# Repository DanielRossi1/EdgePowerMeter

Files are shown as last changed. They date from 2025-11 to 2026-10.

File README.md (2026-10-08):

# EdgePowerMeter ⚡

<div align="center">

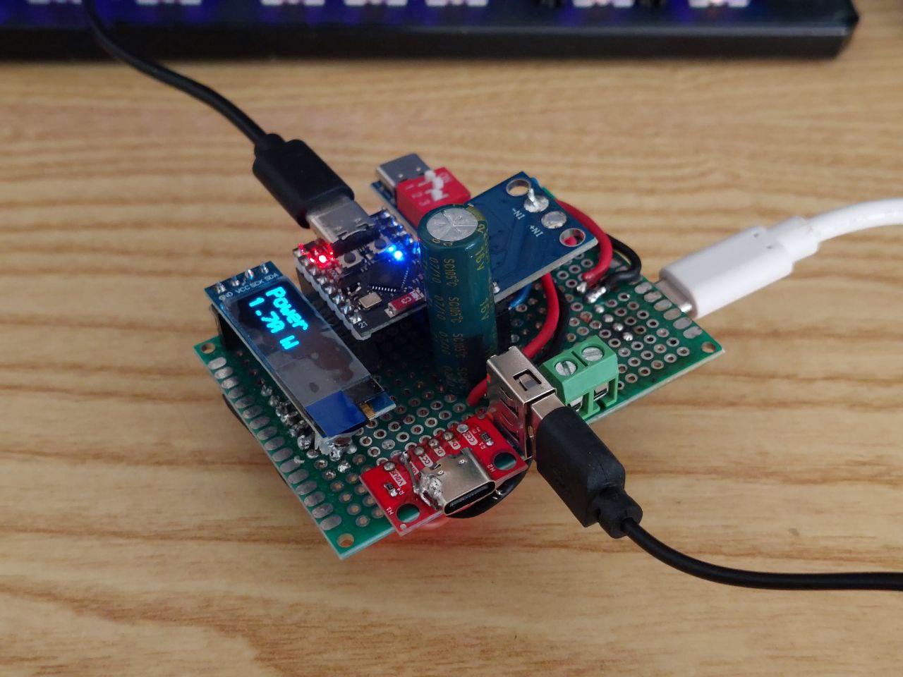
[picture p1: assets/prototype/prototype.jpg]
EdgePowerMeter Hardware


**A precision power monitoring system for embedded AI workloads**


[]()
[]()

</div>

---

## 📋 Table of Contents

- [Overview](#-overview)
- [Features](#-features)
- [Desktop Application](#-desktop-application)
- [Hardware](#-hardware)
- [Installation](#-installation)
- [Building](#-building)
- [Usage](#-usage)
- [Safety Warning](#-safety-warning)
- [License](#-license)

---

## 🔎 Overview

**EdgePowerMeter** is a complete power monitoring solution designed to measure voltage, current, and power consumption of embedded devices running AI inference workloads. Perfect for benchmarking FPS-per-Watt (FPS/W) efficiency of machine learning models at the edge.

### Why EdgePowerMeter?

- **Precision Measurements**: INA226 power monitor with configurable averaging
- **Real-time Visualization**: Modern desktop app with live graphs
- **Data Export**: CSV and PDF report generation
- **Timestamped Logs**: DS3231 RTC for accurate time synchronization
- **Open Source**: Full hardware schematics and software included

---

## ✨ Features

### Hardware
- 🔋 **INA226** high-precision power monitor (I²C)
- 🕐 **DS3231** real-time clock for accurate timestamps
- 📺 **SSD1306** OLED display (128×32) for live readings
- ⚡ **ESP32-C3** microcontroller with WiFi/BLE capability
- 🔧 **0.01Ω shunt** resistor for current sensing

### Software
- 📊 Real-time voltage, current and power plots with peak-preserving decimation (smooth even after hours at ~1 kHz)
- ⏱️ **Device-clock time base** (firmware 2.x): sample spacing, energy and spectrum are not distorted by USB/PC latency
- 🧮 **Lost-sample detection** (sequence numbers) and real-time energy, charge, min/max and average power
- 🎛️ **Remote sensor configuration**: INA226 averaging and conversion times, presets from ~2 Hz to ~900 Hz, saved on the device
- 🕐 **Clock sync** of the DS3231 with the PC, with live device–PC offset
- 🎯 **Calibration** in the app: shunt value, current zero ("zero now"), voltage/current gain and offset
- 📐 **Analysis page**: selectable range, per-quantity statistics, power supply quality (ripple, noise, load regulation, settling time) and frequency spectrum
- 🚩 **Markers**: press `M` (or right-click the plot) to mark events; every segment between markers gets duration, energy, average and peak power
- 🏁 **Benchmark mode**: energy per inference, inferences per joule and FPS/W, also net of the idle power
- 💽 **Continuous recording**: every acquisition is saved while it runs to a visible CSV file (crash-safe, no duplicates, no hidden files)
- 💾 CSV export/import (decimal comma, date/time or Unix time) and PDF reports with vector charts
- 🌍 **5 languages** (English, Italiano, Español, Français, Deutsch), automatically selected from the system, translated offline with a local model
- 🎨 Dark, light or system theme, configurable units, digits, refresh rate, time window and more
- 🔌 **Safe auto-reconnect**: after an unplug the recording continues; a manual Stop never restarts it
- ⌨️ Keyboard shortcuts (Ctrl+R, Ctrl+O, Ctrl+E, Ctrl+P, Ctrl+1…5)

---

## 🖥️ Desktop Application

The EdgePowerMeter desktop application provides a modern interface for real-time power monitoring and data analysis.

The window has a navigation rail with five pages: **Live**, **Analysis**,
**Device**, **Settings** and **About** (Ctrl+1…5).

> The screenshots show simulated demo data (idle → model load → inference at
> 10 FPS on a ~5 V rail); the Device page is taken from a real sensor.

### Live

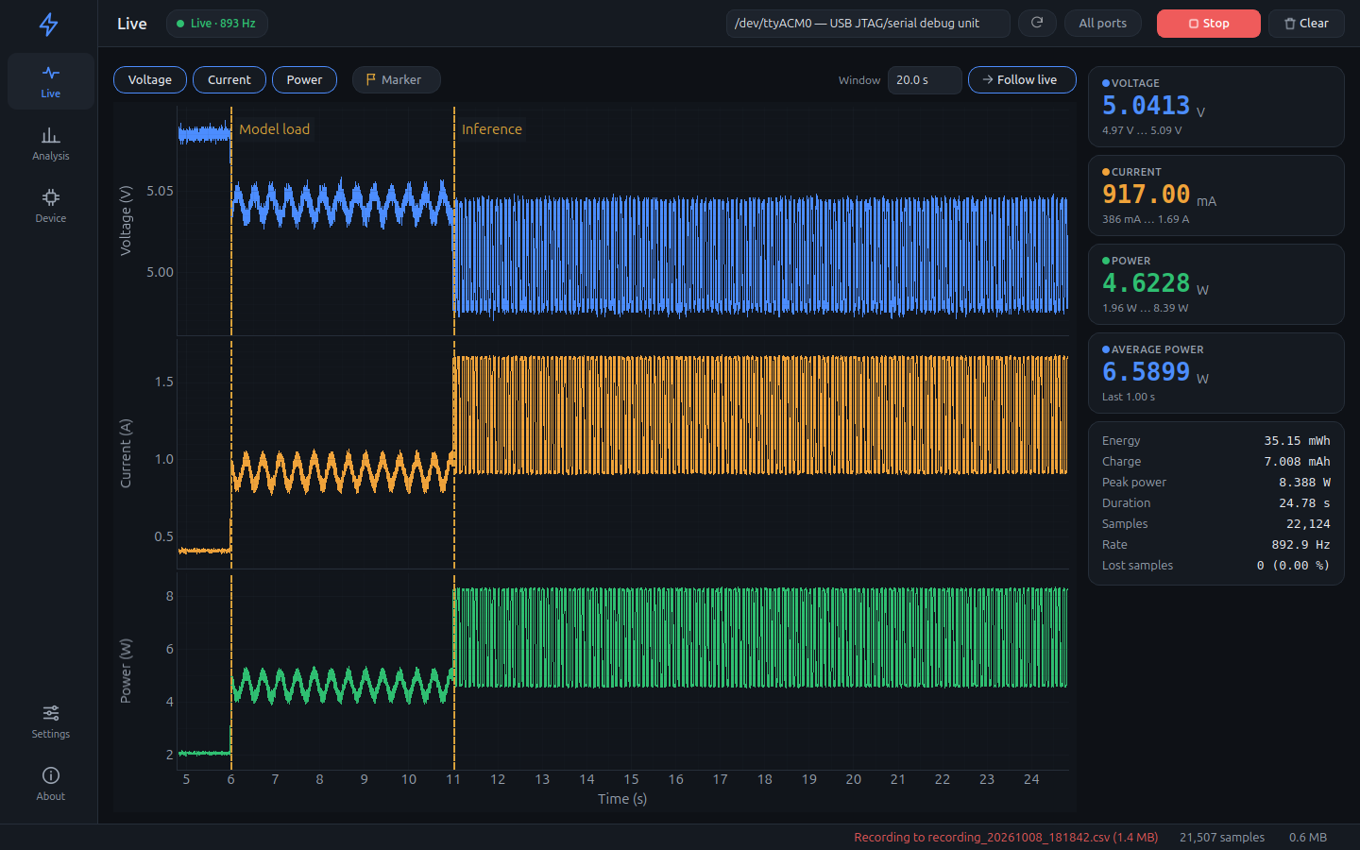
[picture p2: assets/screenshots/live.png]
Live page


Three synchronized plots (voltage, current, power) with value tiles and running
totals: energy, charge, peak power, duration, sample rate and lost samples.
Drag the plots to look back and use the mouse wheel to change the time window;
**Follow live** returns to the latest data. Press `M` (or the **Marker**
button, or right-click a plot) to mark an event. Every acquisition is written
to a CSV file while it runs, as shown in the status bar.

### Analysis

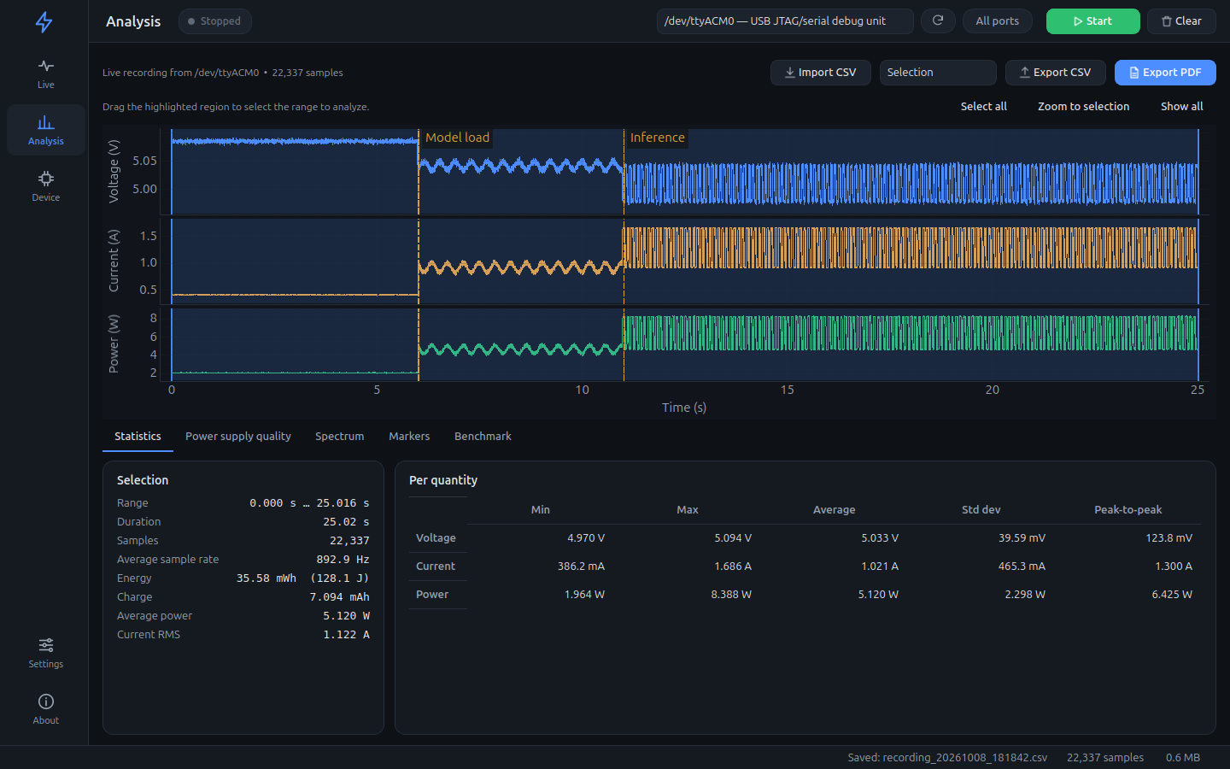
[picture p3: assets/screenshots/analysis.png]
Analysis page


Drag the highlighted region to select the range to analyze (or **Select all**),
then switch between the tabs below the plot. **Statistics** gives duration,
energy, charge, average power and current RMS of the selection plus min, max,
average, standard deviation and peak-to-peak of each quantity.

**Markers** turns the marks into segments, each with its start, duration,
average and peak power, energy and charge; click a row to select that segment.

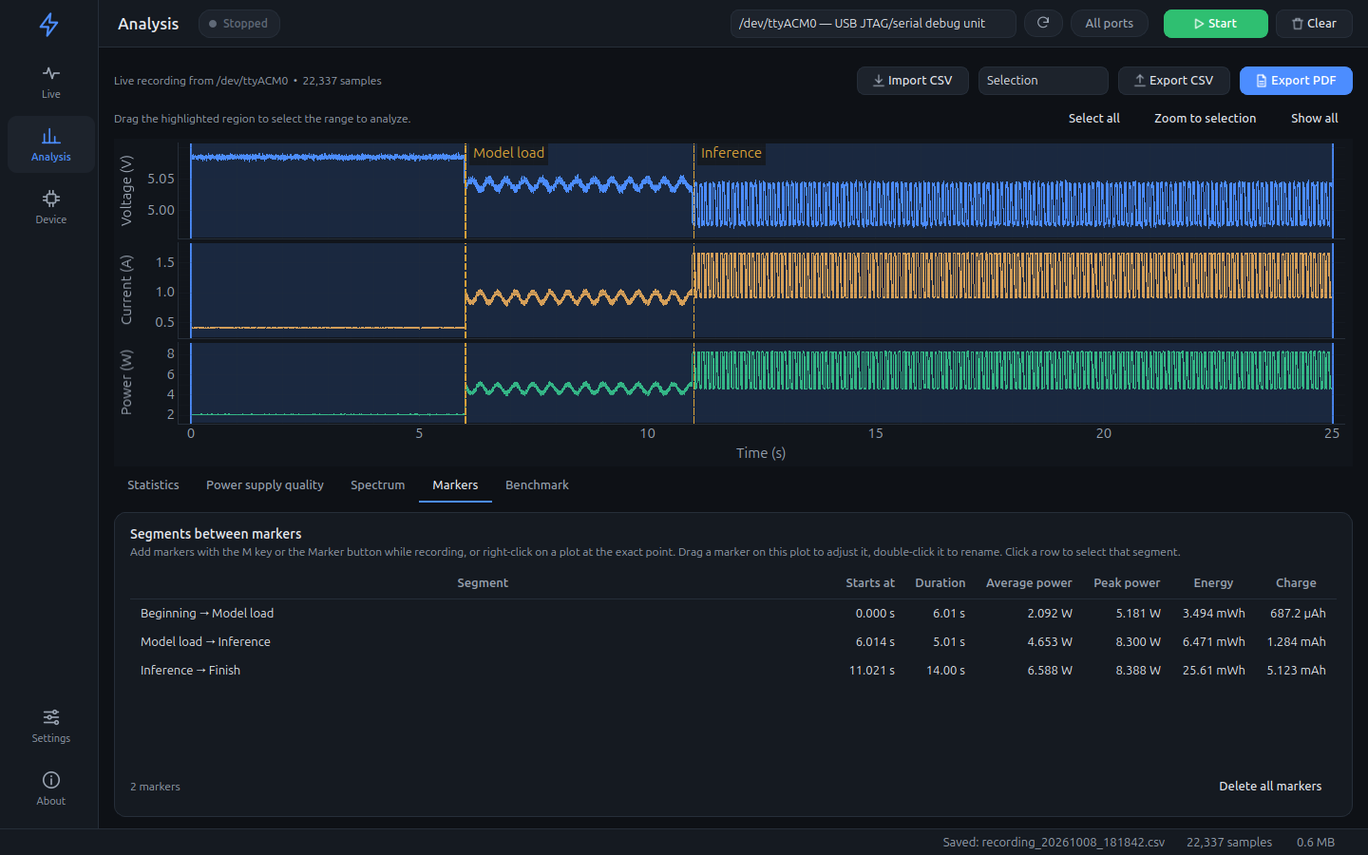
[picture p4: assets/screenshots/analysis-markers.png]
Markers tab


**Benchmark** computes energy per inference, inferences per joule and
throughput per watt (FPS/W) for the selection or a segment, also net of the
idle power measured in another segment, and can add them to the PDF report.

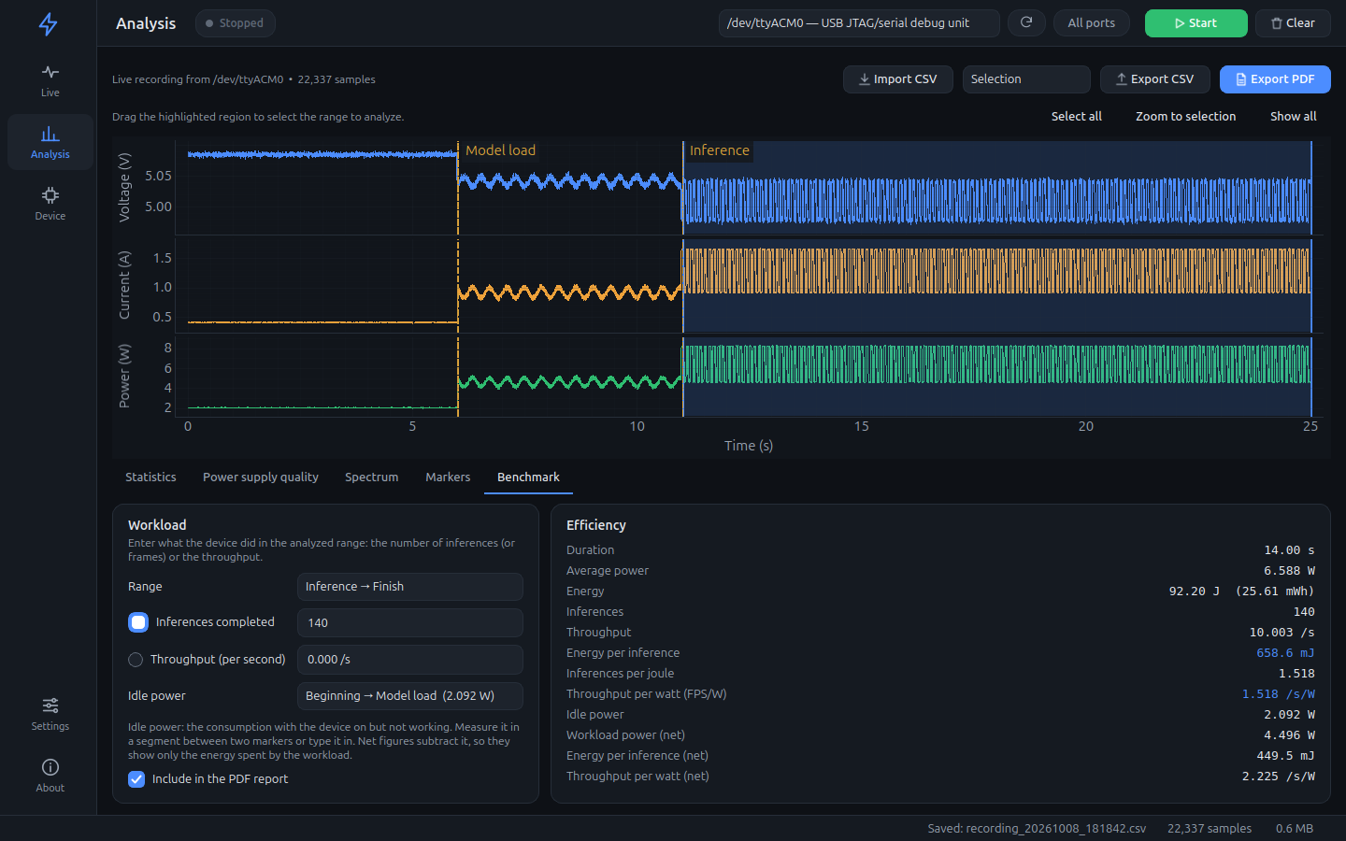
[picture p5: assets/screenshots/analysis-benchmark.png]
Benchmark tab


**Spectrum** shows where the load variation energy is concentrated (periodic
bursts, throttling cycles, regulator ripple) with the dominant frequencies;
**Power supply quality** rates the supply rail: voltage range, ripple, RMS
noise, load regulation and settling time.

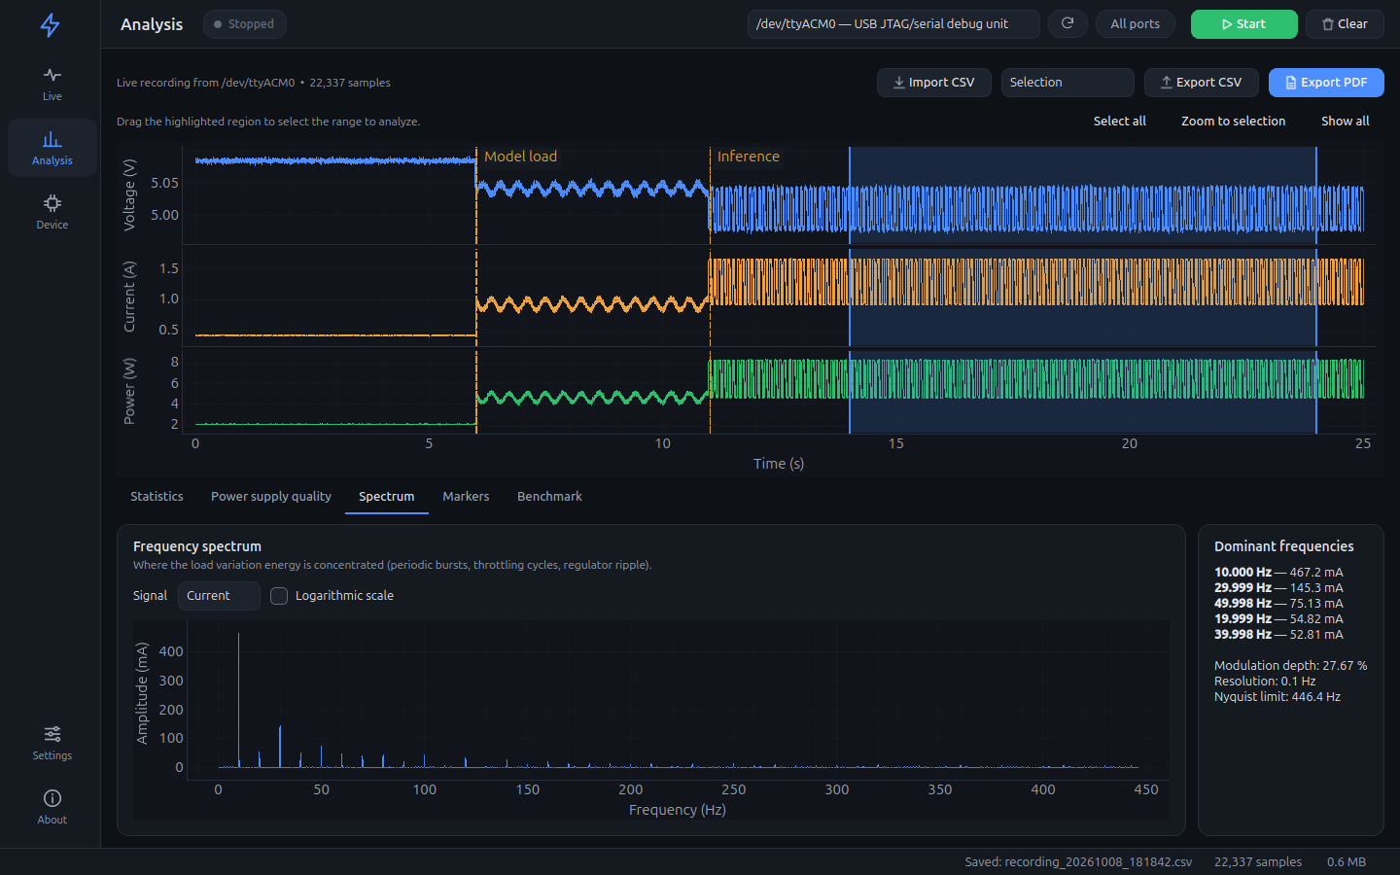
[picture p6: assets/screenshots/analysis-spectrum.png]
Spectrum tab


**Export CSV** and **Export PDF** work on the selection or the whole
recording; PDF reports include vector charts, statistics, markers, supply
quality, spectrum and benchmark results.

### Device

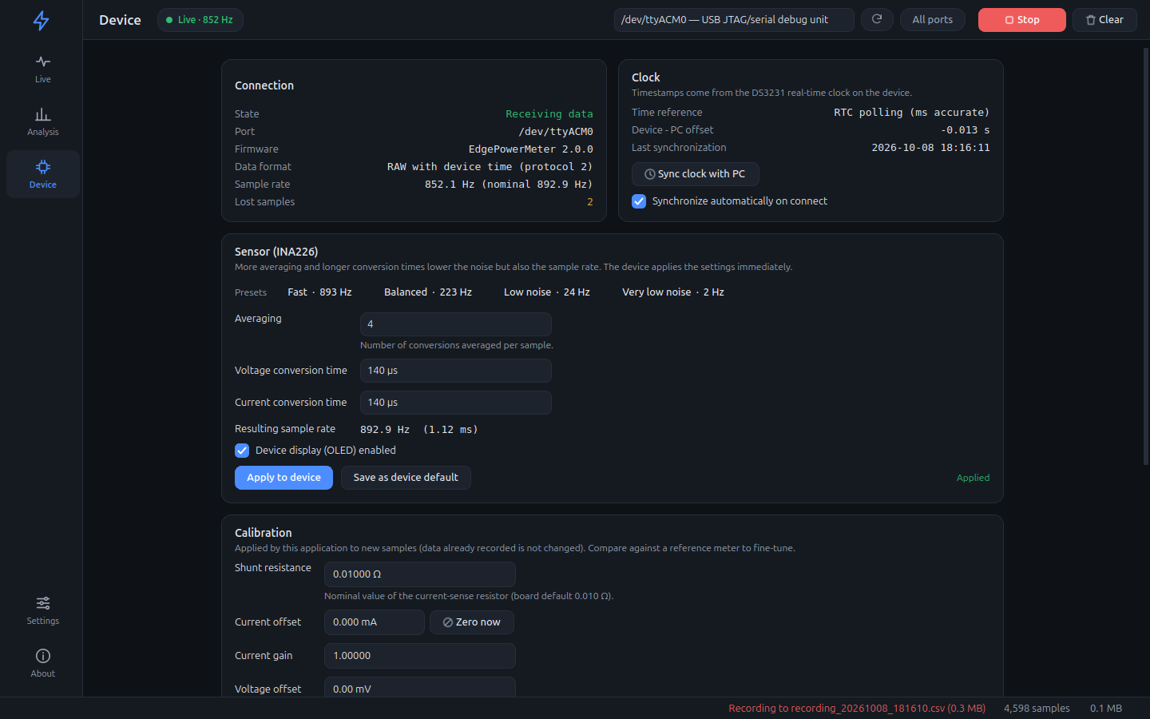
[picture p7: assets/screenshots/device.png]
Device page


Connection and firmware details, clock synchronization of the DS3231 with the
PC, INA226 averaging and conversion times (with presets from ~2 Hz to ~900 Hz,
applied immediately and optionally saved on the device) and calibration of
shunt value, current zero, gain and offset. Remote configuration and clock
sync need firmware 2.x.

### Settings

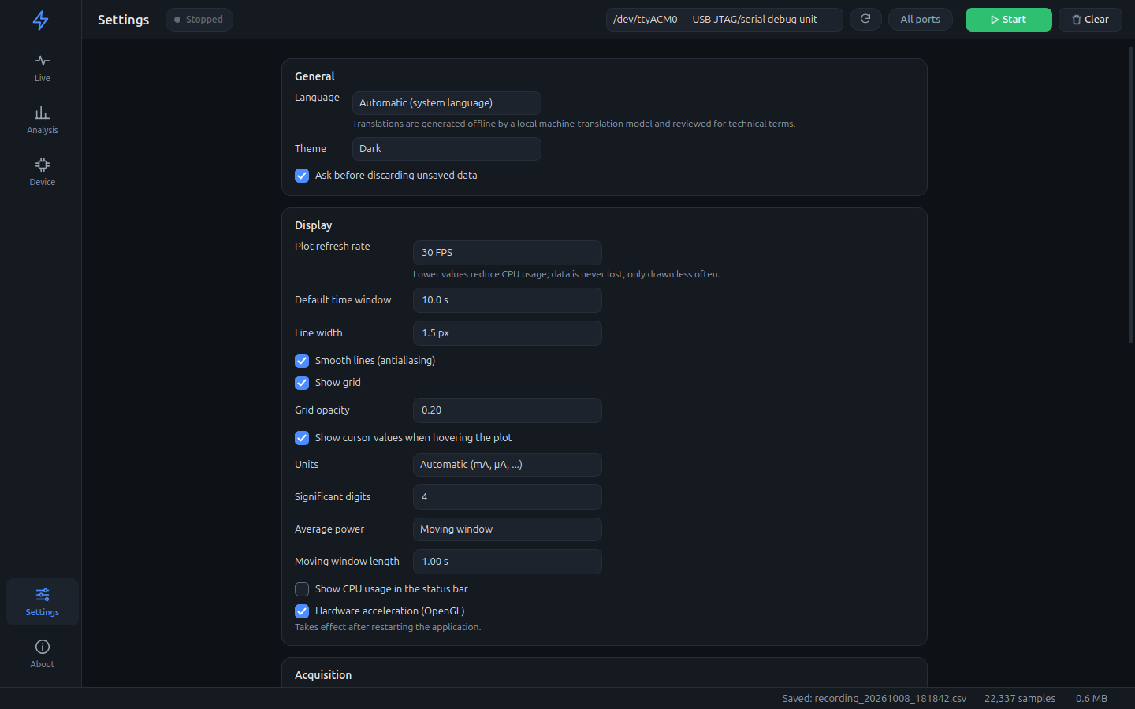
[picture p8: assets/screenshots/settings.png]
Settings page


Language, theme, plot refresh rate and time window, line width, grid, units,
significant digits, average-power mode, hardware acceleration and acquisition
options.

---

## 🧩 Hardware

### Components

| Component | Model | I²C Address | Description |
|---|---|---|---|
| MCU | ESP32-C3 SuperMini | - | Main microcontroller |
| Power Monitor | INA226 | 0x40 | Voltage/Current sensing |
| Display | SSD1306 | 0x3C | 128×32 OLED |
| RTC | DS3231 | 0x68 | Real-time clock |
| Shunt | R2512 | - | 0.01Ω current sense |

### Project Files

| File | Description |
|---|---|
| `Manufacture/BOM.csv` | Bill of Materials |
| `Manufacture/PickAndPlace.csv` | Pick and Place coordinates |
| `Schematics/EdgePowerMeter.fzz` | Fritzing schematic |
| `Schematics/EdgePowerMeter_bom.csv` | Schematic BOM |
| `firmware/firmware.ino` | Arduino firmware with libraries |

### Wiring Overview

All I²C devices share a common bus:
- **SDA**: GPIO8 (ESP32-C3)
- **SCL**: GPIO9 (ESP32-C3)
- **VCC**: 3.3V common rail
- **GND**: Common ground

The INA226 monitors voltage across the shunt resistor via `VIN+` (high side) and `VIN-` (low side).

---

## 📦 Installation

### Pre-built Binaries

Download the latest release for your platform from the [Releases](https://github.com/DanielRossi1/EdgePowerMeter/releases) page:

| Platform | File |
|---|---|
| Linux (Snap Store) | `sudo snap install edgepowermeter` |
| Linux (Debian/Ubuntu) | `edgepowermeter_x.x.x_amd64.deb` |
| Linux (Other) | `EdgePowerMeter` (standalone) |
| Windows | `EdgePowerMeter.exe` |
| macOS (Intel) | `EdgePowerMeter-macos-x86_64.zip` |
| macOS (Apple Silicon) | `EdgePowerMeter-macos-arm64.zip` |

#### Linux (Snap Store) - Recommended
```bash
sudo snap install edgepowermeter
sudo snap connect edgepowermeter:raw-usb  # Required for USB serial access
edgepowermeter
```

#### Linux (.deb)
```bash
sudo dpkg -i edgepowermeter_1.0.0_amd64.deb
edgepowermeter
```

#### Linux (standalone)
```bash
chmod +x EdgePowerMeter
./EdgePowerMeter
```

### From Source

```bash
# Clone the repository
git clone https://github.com/DanielRossi1/EdgePowerMeter.git
cd EdgePowerMeter

# Create a virtual environment and install the app with its dependencies
python3 -m venv .venv
.venv/bin/pip install -e .          # PySide6, pyqtgraph, pyserial, reportlab, numpy, PyOpenGL

# Run the application
.venv/bin/python run.py
```

### Firmware

#### Arduino IDE
1. Install ESP32 board support
2. Install required libraries:
   - `Adafruit_GFX`
   - `Adafruit_SSD1306`
   - `RTClib` by Adafruit
   (the Rob Tillaart `INA226` library is no longer needed since firmware 2.0)
3. Open `firmware/firmware.ino`
4. Select board `ESP32C3 Dev Module` and set **USB CDC On Boot: Enabled**
5. Upload

#### Arduino CLI

```bash
arduino-cli compile --fqbn esp32:esp32:esp32c3:CDCOnBoot=cdc firmware
arduino-cli upload -p /dev/ttyACM0 --fqbn esp32:esp32:esp32c3:CDCOnBoot=cdc firmware
```

The desktop app also works with firmware 1.x, but device time, lost-sample
detection, sensor configuration and clock sync require firmware 2.x.

---

## 🔨 Building

To build standalone executables for distribution:

```bash
# Install build dependencies
pip install pyinstaller

# Build executable + .deb package (Linux)
python build.py all

# Or just the executable
python build.py exe
```

Output files are created in `dist/`:
- `EdgePowerMeter` - Standalone executable
- `edgepowermeter_1.0.0_amd64.deb` - Debian package

📖 **See [docs/BUILD.md](docs/BUILD.md) for detailed build instructions**, including:
- Building on Windows and macOS
- Creating installers
- CI/CD integration
- Troubleshooting

---

## 🚀 Usage

### Quick Start

1. **Connect hardware** to your computer via USB
2. **Launch the app**: `python run.py` or run the executable
3. **Select serial port** from the dropdown
4. **Click Start** to begin recording

### Serial Output Format

At boot the firmware prints human-readable CSV (also what firmware 1.x sends),
so it can be used with any serial monitor:

```
Timestamp,Voltage[V],Current[A],Power[W]
2026-10-08 12:34:56.123,5.01250,0.250000,1.253125
```

The desktop app performs a handshake and switches the device to a compact RAW
format with device time in µs, a sequence number and the raw INA226 registers.
See **[docs/PROTOCOL.md](docs/PROTOCOL.md)** for the full protocol and the
command set (`HELLO`, `GET`, `SET AVG/VCT/ICT/OLED/STREAM/SHUNT`, `SYNC`, `SAVE`).

### Reading Serial Data (Linux)

```bash
screen /dev/ttyACM0 2000000
```

### Calculating FPS per Watt

```
FPS/W = Inference_FPS / Average_Power_W
```

**Example**: 30 FPS inference with 2.5W average = **12 FPS/W**

---

## ⚠️ Safety Warning

> **⚠️ IMPORTANT**: This project involves electrical connections. Incorrect wiring can cause damage, fire, or injury.

### Precautions

- ❌ **NOT designed for AC voltages**
- 🔌 Disconnect power before changing connections
- 🔍 Verify polarity with a multimeter before powering
- ⚡ Use appropriate fuses for your application
- 💧 Keep device dry and away from conductive materials
- 👨‍🔧 Seek professional help if unsure

**The author assumes no responsibility for damage or injury resulting from improper use.**

---

## 🛠️ Configuration

### Sensor and Calibration

With firmware 2.x, averaging and conversion times are set from the **Device**
page of the app (or with serial commands) and can be stored on the device with
*Save as device default*. Calibration (shunt value, zero offset, gain) is
applied by the app, so no reflashing is needed.

### RTC Synchronization

Use *Sync clock with PC* on the Device page (or enable automatic sync on
connect). `FORCE_RTC_UPDATE = true` in the firmware still forces a one-time sync
to the compile time.

---

## 📊 Specifications

| Parameter | Value |
|---|---|
| Voltage Range | 0 - 36V |
| Current Range | ±3.2A (with 0.01Ω shunt) |
| Resolution | 1.25 mV / 0.25 mA (2.5 µV shunt LSB) |
| Sampling Rate | ~2 Hz – ~900 Hz (configurable, default ~893 Hz) |
| Time Stamping | Device µs clock, anchored to the DS3231 SQW (±2 ppm) |
| Serial | Native USB-CDC (2000000 baud nominal) |
| Display Update | 4 Hz (non-blocking) |

---

## 📁 Project Structure

```
EdgePowerMeter/
├── firmware/                 # ESP32-C3 firmware (Arduino sketch)
│   ├── firmware.ino          # Sampling loop, protocol, commands
│   ├── INA226Lite.h/cpp      # Minimal INA226 driver
│   ├── PrecisionTime.h/cpp   # DS3231 SQW time anchors
│   └── OLEDStatus.h/cpp      # Non-blocking OLED display
├── app/
│   ├── main.py               # Bootstrap (GPU preflight, QApplication)
│   ├── core/                 # Samples store, statistics, PSU quality, spectrum, settings
│   ├── serial/               # Port I/O, protocol decoder, reader thread
│   ├── export/               # CSV import/export, PDF report, unit formatting
│   ├── i18n/                 # Runtime translations + generated catalogs
│   └── ui/                   # Main window, controller, pages, widgets, theme
├── tools/i18n/               # Offline machine-translation tool
├── tests/                    # pytest suite (headless, fake device)
├── docs/                     # BUILD, HARDWARE, SOFTWARE, PROTOCOL
├── Manufacture/              # PCB production files
└── Schematics/               # Circuit diagrams
```

---

## 🤝 Contributing

Contributions are welcome! Please feel free to submit issues and pull requests.

### TODO

- [ ] 3D printed enclosure design
- [ ] Mobile app companion
- [ ] Data logging to SD card
- [ ] Improved PCB design

---

## 📜 License

This project is licensed under the **Apache License 2.0** - see the [LICENSE](LICENSE) file for details.

---

<div align="center">

**Made with ❤️ for the embedded AI community**

⭐ Star this repo if you find it useful!

</div>

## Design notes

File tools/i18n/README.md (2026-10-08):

# Translations (i18n)

The app's UI text is written in English and wrapped in `tr()`:

```python
from app.i18n import tr, N_
button.setText(tr("Start"))
status.setText(tr("No data received for {seconds}s", seconds=5))
COLUMNS = [N_("Voltage"), N_("Current")]  # marked now, translated later with tr(col)
```

At runtime `app/i18n` only reads `app/i18n/locales/<code>.json`. Those catalogs
are generated **offline, on your machine**, with Argos Translate models run
through CTranslate2 (no cloud service, no torch).

## Workflow

```bash
# one-time setup (separate venv, gitignored)
python3 -m venv tools/i18n/.venv
tools/i18n/.venv/bin/pip install -r tools/i18n/requirements.txt

# after changing UI strings
tools/i18n/.venv/bin/python tools/i18n/translate.py extract              # -> tools/i18n/strings.json
tools/i18n/.venv/bin/python tools/i18n/translate.py translate --prune    # fills locales/*.json
tools/i18n/.venv/bin/python tools/i18n/translate.py check                # missing/stale report
```

The first `translate` downloads the en→it/es/fr/de models (~85–100 MB each)
into `~/.cache/edgepowermeter-i18n`. After that it runs fully offline.

Only strings missing from a catalog are machine-translated, so existing
entries (including hand edits) are kept. `--prune` drops entries whose
English source no longer exists.

## Fixing bad translations

Machine translation handles sentences well but often gets short UI labels
and electrical terms wrong ("Current" → "Actuellement", "Shunt" → "shock").
Put corrections in `app/i18n/overrides/<code>.json` (`{english: fixed}`).
Overrides are merged on every `translate` run and always win over the
machine output.

## Protected text

`{placeholders}`, bracketed units (`[V]`, `(mA)`), units after a value
(`5 s`, `{value} V`) and technical names (INA226, CSV, PDF, Hz, mW, ...) are
swapped for tokens before translation and restored afterwards. If the model
mangles a placeholder, the string is left in English and a warning is printed.

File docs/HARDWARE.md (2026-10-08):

# EdgePowerMeter Hardware Documentation

This document provides detailed information about the EdgePowerMeter hardware design.

## Table of Contents

1. [Overview](#overview)
2. [Components](#components)
3. [Circuit Design](#circuit-design)
4. [Wiring Schematic](#wiring-schematic)
5. [PCB Files](#pcb-files)
6. [Assembly](#assembly)
7. [Calibration](#calibration)
8. [Troubleshooting](#troubleshooting)

---

## Overview

EdgePowerMeter is a precision power measurement device based on the INA226 current/voltage monitor. It's designed to measure power consumption of embedded devices, particularly for AI inference benchmarking.

### Prototype

EdgePowerMeter Prototype

*The assembled EdgePowerMeter prototype with ESP32-C3, INA226, DS3231 RTC, and SSD1306 OLED display.*

### Key Specifications

| Parameter | Value | Notes |
|---|---|---|
| Input Voltage Range | 0 - 36V | Bus voltage measurement |
| Current Range | ±3.2A | With 0.01Ω shunt |
| Voltage Resolution | 1.25mV | 16-bit ADC |
| Current Resolution | 0.25mA | Shunt LSB 2.5µV / 0.01Ω |
| Power Calculation | Host | V × I computed per sample from raw registers |
| Sampling Rate | up to ~890 Hz | Set by INA226 averaging and conversion times (default 4 × (140+140) µs) |
| Interface | Native USB-CDC | Protocol v2, see [PROTOCOL.md](PROTOCOL.md) |

---

## Components

### Bill of Materials

| Ref | Component | Value | Package | Description |
|-----|---|---|---|---|
| U1 | ESP32-C3 | SuperMini | Module | Microcontroller |
| U2 | INA226 | - | Module | Power monitor |
| U3 | SSD1306 | 128×32 | Module | OLED display |
| U4 | DS3231 | - | Module | Real-time clock |
| R1 | Shunt | 0.01Ω | R2512 | Current sense |

### Component Details

#### ESP32-C3 SuperMini

- **CPU**: 32-bit RISC-V @ 160MHz
- **Memory**: 400KB SRAM, 4MB Flash
- **Connectivity**: WiFi, BLE 5.0
- **GPIO**: 13 available pins
- **USB**: Native USB-C

#### INA226

- **Type**: Bidirectional current/power monitor
- **Interface**: I²C (address 0x40)
- **ADC**: 16-bit
- **Features**:
  - Programmable averaging (1-1024 samples)
  - Programmable conversion time
  - Alert functionality

#### DS3231

- **Type**: Precision RTC
- **Interface**: I²C (address 0x68)
- **Accuracy**: ±2ppm (0°C to +40°C)
- **Features**:
  - Temperature compensation
  - Battery backup
  - Alarm functions

#### SSD1306 OLED

- **Resolution**: 128×32 pixels
- **Interface**: I²C (address 0x3C)
- **Color**: Monochrome (white/blue)
- **Viewing Angle**: >160°

---

## Circuit Design

### Wiring Schematic

The complete wiring diagram for EdgePowerMeter:

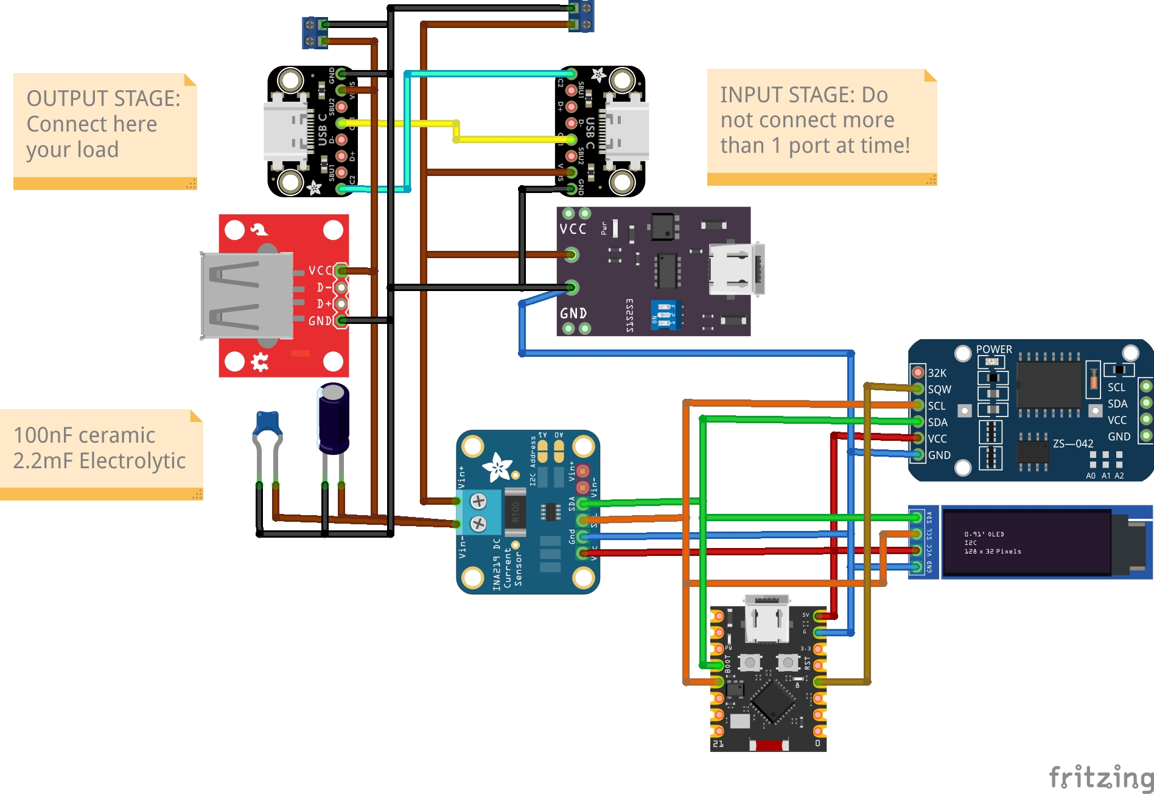
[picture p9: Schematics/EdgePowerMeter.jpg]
EdgePowerMeter Wiring Schematic


*Complete wiring schematic showing all connections between ESP32-C3, INA226, DS3231, and SSD1306.*

### Vector Schematic

For high-resolution printing or editing, an SVG version is also available:

📄 **SVG File**: [`Schematics/EdgePowerMeter.svg`](../Schematics/EdgePowerMeter.svg)

### Block Diagram

```
                    ┌─────────────┐
                    │   DS3231    │
                    │     RTC     │
                    └──────┬──────┘
                           │ I²C
┌─────────┐    ┌───────────┼───────────┐    ┌─────────┐
│  LOAD   │◄───┤         ESP32-C3      ├───►│   USB   │
│ DEVICE  │    │      (SuperMini)      │    │ (Data)  │
└────┬────┘    └───────────┬───────────┘    └─────────┘
     │                     │ I²C
     │         ┌───────────┼───────────┐
     │         │                       │
     │    ┌────┴────┐            ┌─────┴─────┐
     │    │ INA226  │            │  SSD1306  │
     │    │ Power   │            │   OLED    │
     │    │ Monitor │            │  Display  │
     │    └────┬────┘            └───────────┘
     │         │
     └─────────┤
        Shunt  │
       0.01Ω   │
               │
         ┌─────┴─────┐
         │   POWER   │
         │   SOURCE  │
         └───────────┘
```

### I²C Bus

All I²C devices share a common bus:

| Signal | ESP32-C3 GPIO | Pull-up |
|---|---|---|
| SDA | GPIO8 | 4.7kΩ |
| SCL | GPIO9 | 4.7kΩ |

### SQW Precision Timing

The DS3231 SQW (Square Wave) output provides a precise 1Hz signal for millisecond-accurate timestamps:

| Signal | ESP32-C3 GPIO | Pin Label | Function |
|---|---|---|---|
| SQW | GPIO3 | A3 | 1Hz interrupt for time sync |

**How it works:**
1. DS3231 outputs a 1Hz square wave on SQW pin; its falling edge marks the start of a new RTC second
2. ESP32 captures the falling edge in an interrupt with `esp_timer_get_time()` (µs resolution)
3. Shortly after, when the sampling loop has spare time, the RTC second is read and paired with the edge time: this is a *time anchor*
4. Every sample carries the device µs timestamp of its conversion; the host maps it to wall-clock time through the latest anchor (in RAW mode the anchors are sent once per second as `T` lines)
5. Result: µs-resolution sample timing with the DS3231's ±2ppm long-term accuracy

If no SQW edge is detected (pin not wired), the firmware falls back to polling the RTC seconds register around the expected boundary (≈ ms accuracy); the OLED status line then shows `RTC` instead of `SQW`.

### I²C Device Addresses

| Device | Address | Function |
|---|---|---|
| INA226 | 0x40 | Power monitor |
| SSD1306 | 0x3C | OLED display |
| DS3231 | 0x68 | Real-time clock |

### Power Rails

| Rail | Voltage | Source | Consumers |
|---|---|---|---|
| 3.3V | 3.3V | ESP32-C3 LDO | All I²C modules |
| VBUS | 5V | USB | ESP32-C3 |
| VLOAD | 0-36V | External | DUT (Device Under Test) |

### INA226 Connection Detail

```
POWER SOURCE (+) ──────────────┬─────────────── VIN+ (INA226)
                               │
                            ┌──┴──┐
                            │SHUNT│ 0.01Ω
                            │R2512│
                            └──┬──┘
                               │
POWER SOURCE (-) ──┬───────────┴─────────────── VIN- (INA226)
                   │
                   └─────────────────────────── LOAD (-)

LOAD (+) ──────────────────────────────────── Connected at VIN- side
```

**Important**: The load connects after the shunt resistor to measure current flowing through it.

---

## PCB Files

### Manufacturing Files

Located in `Manufacture/` directory:

| File | Description |
|---|---|
| [`BOM.csv`](../Manufacture/BOM.csv) | Bill of Materials for PCB |
| [`PickAndPlace.csv`](../Manufacture/PickAndPlace.csv) | Component placement coordinates |
| `gerber.zip` | Gerber files for PCB fabrication |

### Schematic Files

Located in `Schematics/` directory:

| File | Description |
|---|---|
| [`EdgePowerMeter.fzz`](../Schematics/EdgePowerMeter.fzz) | Fritzing project file |
| [`EdgePowerMeter.jpg`](../Schematics/EdgePowerMeter.jpg) | Wiring diagram (JPEG) |
| [`EdgePowerMeter.svg`](../Schematics/EdgePowerMeter.svg) | Wiring diagram (SVG) |
| [`EdgePowerMeter_bom.csv`](../Schematics/EdgePowerMeter_bom.csv) | Component BOM |

---

## Assembly

### Required Tools

- Soldering iron (temperature controlled)
- Fine tip (chisel or conical)
- Solder (0.5mm recommended)
- Flux (no-clean)
- Tweezers
- Multimeter
- Heat shrink tubing

### Assembly Steps

1. **Prepare Modules**
   - Verify all modules with multimeter
   - Check I²C addresses match expected values

2. **Wire I²C Bus**
   ```
   Connect in parallel:
   - SDA: All modules SDA pins
   - SCL: All modules SCL pins
   - VCC: All modules VCC pins (3.3V)
   - GND: All modules GND pins
   ```

3. **Install Shunt Resistor**
   - Use R2512 package (0.01Ω)
   - Ensure good solder joints (low resistance)
   - Verify with multimeter (should read ~0.01Ω)

4. **Connect INA226**
   - VIN+ to power source positive
   - VIN- to load positive (after shunt)

5. **Final Connections**
   - USB-C for programming and data
   - Optional: External power for higher currents

### Wiring Reference

Refer to the schematic for exact connections:

Wiring Reference

### Verification Checklist

- [ ] No shorts between VCC and GND
- [ ] I²C pull-ups installed
- [ ] All I²C addresses correct
- [ ] Shunt resistance verified
- [ ] USB connection working
- [ ] OLED displays on power-up

---

## Firmware

The sketch lives in `firmware/` (version 2.x, serial protocol v2 documented in
[PROTOCOL.md](PROTOCOL.md)).

| File | Purpose |
|---|---|
| `firmware.ino` | Main loop: sampling, serial output, command parser, NVS settings |
| `INA226Lite.h/.cpp` | Minimal INA226 driver (raw registers, conversion-ready polling) |
| `PrecisionTime.h/.cpp` | DS3231 time anchors (SQW interrupt, polling fallback) |
| `OLEDStatus.h/.cpp` | SSD1306 display with non-blocking chunked frame transfer |

**Required libraries:** `RTClib`, `Adafruit SSD1306`, `Adafruit GFX Library`
(and their dependency `Adafruit BusIO`). The Rob Tillaart `INA226` library is
**no longer required**.

**Build** (board *ESP32C3 Dev Module*, *USB CDC On Boot: Enabled*):

```bash
arduino-cli compile --fqbn esp32:esp32:esp32c3:CDCOnBoot=cdc firmware
arduino-cli upload -p /dev/ttyACM0 --fqbn esp32:esp32:esp32c3:CDCOnBoot=cdc firmware
```

**How sampling works:**
- The INA226 runs in continuous shunt+bus mode. The firmware polls its
  conversion-ready flag (the ALERT pin is not wired) and reads the shunt and
  bus registers only when a new conversion is available, so every sample is a
  fresh, non-duplicated conversion with its own µs timestamp.
- Polling starts at ~85% of the conversion period; the time before that is used
  for RTC reads and for the OLED, whose 512-byte frames are sent in 16-byte
  chunks between conversions instead of one ~13 ms blocking transfer.
- If the host stops reading, data lines are dropped instead of blocking; the
  sequence number keeps counting so the app can report lost samples.
- `loop()` never returns: the Arduino core otherwise sleeps 5 ms every 2 s
  between `loop()` calls on single-core chips (`yieldIfNecessary()`), which
  dropped ~4 conversions each time. The idle-task watchdog is disabled for
  this reason. Measured on hardware (default settings, no SQW): 0 lines lost
  and ~0.015 % conversions missed, versus ~0.4 % before.
- At boot the device prints `#`-prefixed info lines and the legacy CSV header,
  then streams in CSV mode until the app switches it to RAW mode.

---

## Calibration

With firmware 2.x the device streams the **raw** INA226 shunt and bus
registers (RAW mode); conversion to volts/amps/watts and all calibration
(shunt resistance, current offset, gain factors) happen in the desktop app,
so no reflashing is needed to calibrate.

### Shunt Resistance Calibration

1. Measure the actual shunt resistance with a precision multimeter (4-wire if possible)
2. Enter the measured value in the desktop app settings
3. Optionally store it on the device too (used only for the OLED and the legacy CSV output):
   `SET SHUNT 0.0102` followed by `SAVE`

### Current Zero Offset

1. Remove the load (open circuit)
2. Use the app's zero-offset calibration, which subtracts the measured idle current

### Voltage Scaling

1. Apply a known voltage (precision source)
2. Compare the reading with the reference and set the voltage gain in the app

### INA226 Averaging and Conversion Time

The sample period is `(VBUSCT + VSHCT) × AVG`. Configure it from the app or
with serial commands (`SET AVG <n>`, `SET VCT <µs>`, `SET ICT <µs>`, then
`SAVE` to keep it across reboots):

| AVG | Conversion time (each) | Period | Rate | Noise |
|-----|---|---|---|---|
| 1 | 140 µs | 280 µs | ~3.6 kHz* | Highest |
| 4 (default) | 140 µs | 1.12 ms | ~890 Hz | Low |
| 16 | 140 µs | 4.48 ms | ~220 Hz | Lower |
| 16 | 1100 µs | 35.2 ms | ~28 Hz | Very low |
| 64 | 1100 µs | 140.8 ms | ~7 Hz | Lowest |

\* Faster than the firmware can read and transmit every conversion: some
conversions are skipped (visible as timing gaps on the host). Periods of
about 1 ms or more leave time for the OLED refresh; with shorter periods the
OLED stops updating while sampling.

---

## Troubleshooting

### No Serial Output

1. Check USB connection
2. Verify correct COM port selected
3. Make sure the firmware was built with **USB CDC On Boot: Enabled** (the SuperMini has no USB-UART bridge)
4. Check ESP32-C3 is powered (LED on)
5. Data output may be paused (`SET STREAM 1` resumes it)

### I²C Devices Not Found

1. Check wiring continuity
2. Verify 3.3V power to all modules
3. Confirm pull-up resistors installed
4. Run I²C scanner sketch:
   ```cpp
   #include <Wire.h>
   
   void setup() {
       Wire.begin(8, 9); // SDA, SCL
       Serial.begin(115200);
       
       for(byte addr = 1; addr < 127; addr++) {
           Wire.beginTransmission(addr);
           if(Wire.endTransmission() == 0) {
               Serial.printf("Found: 0x%02X\n", addr);
           }
       }
   }
   
   void loop() {}
   ```

### Incorrect Current Readings

1. Verify shunt resistance value
2. Check current LSB configuration
3. Ensure shunt connections are solid
4. Look for ground loops

### OLED Not Working

1. Verify I²C address (0x3C for 128×32)
2. Check VCC is 3.3V
3. Try different I²C address (0x3D)
4. Check for physical damage

### RTC Wrong Time

1. Check RTC battery
2. Sync the clock from the desktop app (or send `SYNC YYYY-MM-DD HH:MM:SS` over serial)
3. Alternatively set `FORCE_RTC_UPDATE = true` in the firmware, upload, then flash back to `false`

### Power Measurement Inaccurate

1. Calibrate shunt resistance
2. Check for voltage drop in wires
3. Verify load connection point
4. Use shorter, thicker wires

---

## Safety Notes

⚠️ **WARNING**: This device is not isolated. The measurement circuit shares ground with USB.

### Safe Operating Limits

| Parameter | Maximum | Notes |
|---|---|---|
| Bus Voltage | 36V | INA226 limit |
| Continuous Current | 3A | Shunt thermal limit |
| Peak Current | 5A | Brief peaks only |
| Operating Temp | 0-70°C | Ambient |

### DO NOT

- ❌ Exceed 36V bus voltage
- ❌ Connect to AC mains
- ❌ Reverse polarity
- ❌ Create ground loops
- ❌ Operate in wet conditions

---

## References

- [INA226 Datasheet](https://www.ti.com/product/INA226)
- [DS3231 Datasheet](https://www.analog.com/DS3231)
- [ESP32-C3 Technical Reference](https://www.espressif.com/en/products/socs/esp32-c3)
- [SSD1306 Datasheet](https://cdn-shop.adafruit.com/datasheets/SSD1306.pdf)

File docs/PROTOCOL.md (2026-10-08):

# EdgePowerMeter Serial Protocol

Firmware 2.x speaks two output formats over the USB-CDC serial port
(2000000 baud nominal; the baud rate is irrelevant for native USB-CDC):

| Mode  | Purpose | Default at boot |
|---|---|---|
| `CSV` | Legacy, human-readable lines (compatible with app ≤ 1.7) | yes |
| `RAW` | Compact machine format with device time and sequence | no |

The desktop app ≥ 1.8 performs a handshake and switches the device to `RAW`.
Old firmware (1.x) ignores the handshake; the app then falls back to parsing
the legacy CSV format.

All lines are ASCII and terminated by `\n` (a preceding `\r` is tolerated).

## Device → host

### Comment / log lines

Any line starting with `#` is informational and must be ignored by parsers.
(Firmware 1.x used `[INFO] ...`, `[ERROR] ...` and `=== ... ===` lines, which
parsers must ignore as well.)

### Legacy CSV data (mode `CSV`)

```
Timestamp,Voltage[V],Current[A],Power[W]          <- header, printed once
2026-10-08 12:34:56.123,12.3450,0.1234,1.5234
```

Timestamp is the RTC wall-clock time (local time, millisecond resolution).

### Raw data (mode `RAW`)

```
D,<seq>,<t_us>,<bus_raw>,<shunt_raw>
```

| Field | Type | Meaning |
|---|---|---|
| `seq` | uint32 | Conversion counter, +1 for every conversion read from the INA226. Wraps at 2^32. A gap means samples were dropped on the device (e.g. TX buffer full). |
| `t_us` | int64  | Device monotonic time in µs since boot (`esp_timer_get_time()`) at which the conversion-ready flag was observed. Never wraps in practice. |
| `bus_raw` | uint16 | INA226 bus voltage register. LSB = 1.25 mV. |
| `shunt_raw` | int16  | INA226 shunt voltage register (signed). LSB = 2.5 µV. |

The host computes physical values (allowing user calibration):

```
V = bus_raw * 1.25e-3 * voltage_gain + voltage_offset
I = shunt_raw * 2.5e-6 / shunt_ohm * current_gain + current_offset
P = V * I
```

### Time anchor (mode `RAW`)

```
T,<t_us>,<rtc_epoch_s>,<src>
```

Emitted once per second (anchors that fail validation are skipped, so a
second can occasionally have none). `t_us` is the device time of the second boundary,
`rtc_epoch_s` the RTC time at that boundary, as seconds since 1970-01-01
**interpreting the RTC calendar as naive local time** (the RTC holds local
wall-clock time). `src` is `S` when the boundary was captured by the DS3231
SQW interrupt (µs accurate) or `P` when detected by polling (≈ ms accurate).

The host maps any sample to wall-clock time with the most recent anchor:
`wall = rtc_epoch_s + (t_us_sample - t_us_anchor) / 1e6`.

### Command replies

Every command gets exactly one reply line starting with `!`. `<COMMAND>` is
the first word of the command, upper-cased (`!OK SET`, `!OK MODE`,
`!ERR FOO unknown_command`):

```
!OK <COMMAND>
!ERR <COMMAND> <reason>
!HELLO,EdgePowerMeter,<firmware_version>,<protocol_version>
!CFG,avg=<n>,vct=<us>,ict=<us>,shunt=<ohm>,oled=<0|1>,stream=<0|1>,mode=<CSV|RAW>,sqw=<0|1>,period_us=<us>
```

`period_us` is the nominal conversion period: `(vct + ict) * avg`.

Error reasons: `missing_argument`, `invalid_value`, `unknown_parameter`,
`unknown_command`, `i2c_error`, `rtc_unavailable`, `nvs_error`,
`line_too_long` (lines over 95 characters, reported as `!ERR ? line_too_long`).

After `!OK MODE` the device re-sends the latest `T` anchor (RAW) or the CSV
header (CSV). In RAW mode a `T` anchor is also sent right after `!OK SYNC`
(the new time line) and after `!OK SET` for `SET STREAM 1`.

## Host → device commands

Case-insensitive, one per line.

| Command | Effect |
|---|---|
| `HELLO` | Identify. Replies `!HELLO,...`. |
| `GET` | Replies `!CFG,...` with the current configuration. |
| `MODE RAW` / `MODE CSV` | Select output format. |
| `SET AVG <n>` | INA226 averaging: 1, 4, 16, 64, 128, 256, 512, 1024. |
| `SET VCT <us>` / `SET ICT <us>` | Bus / shunt conversion time: 140, 204, 332, 588, 1100, 2116, 4156, 8244. |
| `SET SHUNT <ohm>` | Shunt resistance used for CSV mode and the OLED (RAW is unaffected). Accepted range 0.00001–100 Ω. |
| `SET OLED <0\|1>` | Enable/disable the OLED display. |
| `SET STREAM <0\|1>` | Pause/resume data output. |
| `SYNC YYYY-MM-DD HH:MM:SS` | Set the RTC (local time). Hosts should send it right at a second boundary. The device reads the time back and replies `!ERR SYNC i2c_error` if the write did not take. |
| `SAVE` | Persist AVG/VCT/ICT/SHUNT/OLED to flash (NVS); restored at boot. |

Changing `AVG`, `VCT` or `ICT` restarts the conversion pipeline; `seq` keeps
counting. While `STREAM 0` is active sampling continues (OLED) and `seq` keeps
counting, so hosts must not count the gap after `STREAM 1` as lost samples.

## Data loss accounting

* A `seq` gap means the device read conversions but dropped the lines because
  the USB TX buffer was full (host not reading fast enough).
* With very short conversion periods (below ~0.5 ms, e.g. `AVG 1` at 140 µs)
  the firmware cannot read every conversion; skipped conversions never get a
  `seq` and show up only as `t_us` gaps larger than `period_us`.

## Boot sequence

The device waits up to 1.5 s for the USB host, prints `#` info lines ending
with `# EdgePowerMeter v2.x.y ready (protocol 2)`, then the CSV header and CSV
data. A `HELLO` sent during boot is answered once the main loop starts. If the
INA226 is missing the device keeps running, answers commands, prints
`# ERROR INA226 not found` and retries every 5 s.

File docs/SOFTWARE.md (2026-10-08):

# EdgePowerMeter Software Documentation

Desktop application (Python, PySide6/Qt 6, pyqtgraph) for the EdgePowerMeter
hardware. This document describes the architecture and the main modules.
The serial protocol is specified in [PROTOCOL.md](PROTOCOL.md), the firmware
and hardware in [HARDWARE.md](HARDWARE.md), packaging in [BUILD.md](BUILD.md).

## Table of Contents

- [Architecture](#architecture)
- [Data path](#data-path)
- [Modules](#modules)
- [User interface](#user-interface)
- [Translations](#translations)
- [Settings](#settings)
- [Export formats](#export-formats)
- [Testing](#testing)
- [Troubleshooting](#troubleshooting)

---

## Architecture

```
            USB-CDC                    reader thread                      GUI thread
┌──────────┐  bytes  ┌───────────────────────────────────┐  Samples   ┌──────────────────────────┐
│ ESP32-C3 │ ──────► │ SerialPortHandler (select/os.read)│  batches   │ AcquisitionController     │
│ firmware │ ◄────── │ StreamDecoder  (RAW / legacy CSV) │ ─────────► │  SampleStore (numpy)      │
└──────────┘ commands│ SerialReader   (handshake, watchdog,│  ≤60/s    │  RunningStats             │
                     │                 commands, batching)│           │  reconnect logic          │
                     └───────────────────────────────────┘           └────────────┬─────────────┘
                                                                                  │ signals
                                          ┌───────────────┬───────────────┬───────┴──────┬──────────────┐
                                          │ LivePage      │ AnalysisPage  │ DevicePage   │ SettingsPage │
                                          │ plots, tiles  │ selection,    │ INA226 cfg,  │ all options  │
                                          │               │ PSU, spectrum │ clock, calib │              │
                                          └───────────────┴───────────────┴──────────────┴──────────────┘
```

Design rules:

- **No per-sample work on the GUI thread.** The reader decodes in bulk and
  emits one `Samples` batch per frame; plots redraw at a fixed rate (default
  30 FPS) and only the visible slice is handed to pyqtgraph, which
  peak-downsamples it to the pixel width.
- **Columnar storage.** Samples live in growable numpy columns
  (`SampleStore`, 28 bytes/sample), so hours of 1 kHz data stay in the
  hundreds of MB and every statistic is vectorized.
- **Device time.** With firmware 2.x the time axis comes from the device's µs
  clock, not from when data reached the PC, so USB and GUI latency do not
  distort sample spacing, energy integration or the spectrum.
- **The controller has no widgets.** Connection, reconnection and
  data-retention rules live in `AcquisitionController` and are tested headless.

---

## Data path

1. `SerialPortHandler` opens the port (raw termios file descriptor on Linux,
   pyserial elsewhere) and returns whatever bytes are available.
2. `SerialReader` sends `HELLO` until firmware 2.x answers, then `GET`,
   `MODE RAW` and (optionally) `SYNC` at the next second boundary. If only
   legacy CSV lines arrive for 2.5 s it falls back to firmware-1.x mode.
3. `StreamDecoder` splits lines, converts raw INA226 registers with the
   host-side `Calibration` (shunt, gain, offset), maps device time to wall
   clock using the `T` anchors, counts lost samples (sequence gaps) and missed
   conversions (time gaps), and optionally block-averages N samples.
4. `AcquisitionController` appends batches to the `SampleStore`, updates
   `RunningStats` (energy/charge integration skips disconnection gaps), and
   handles state changes.

Connection rules (see `app/ui/controller.py`):

| Event | Behaviour |
|---|---|
| Start | New recording; the UI asks before discarding unsaved data. |
| Stop | Final. Nothing restarts the acquisition automatically. |
| USB unplugged / port hung up | Data kept. With auto-reconnect, the port is polled every second; on return the recording continues and the time axis is bridged with the real outage duration. |
| No data for the configured timeout | Acquisition stops with an explanatory error. |

---

## Modules

| Module | Purpose |
|---|---|
| `app/core/samples.py` | `Samples` (immutable columnar view) and `SampleStore` (append-only growable store). |
| `app/core/statistics.py` | `Statistics.from_samples()` (vectorized), `RunningStats` (incremental), trapezoidal `integrate_energy()` with gap skipping. |
| `app/core/power_supply_quality.py` | Ripple, RMS noise, stability rating, load regulation and settling time (time-based, sample-rate independent). |
| `app/core/markers.py` | `MarkerList` (ids, segments between markers, append-only CSV lines). |
| `app/core/benchmark.py` | Energy per inference, inferences per joule, throughput per watt (gross / net of idle power). |
| `app/export/recorder.py` | `RecordingWriter`: continuous, crash-safe CSV recording. |
| `app/ui/marker_actions.py` | Shared marker gestures (key, button, context menu, rename, drag). |
| `app/core/spectrum.py` | FFT of the load variation on a uniform resampled grid, Hann window, amplitude-correct peaks. |
| `app/core/settings.py` | `AppSettings` dataclass, QSettings persistence, validation, migration from 1.x. |
| `app/serial/protocol.py` | `StreamDecoder`, `Calibration`, `DeviceConfig`, `DeviceInfo`. Qt-free and unit-tested. |
| `app/serial/serial_reader.py` | `SerialReader` QThread: handshake, commands, clock sync, watchdog, batching. |
| `app/serial/handler.py` | Low-level port I/O; raises `DeviceDisconnected` on hang-up. |
| `app/export/csv_io.py` | CSV export (separator, decimal comma, date/time or Unix time) and import (all layouts written by any app version or by the firmware). |
| `app/export/pdf_report.py` | PDF report with vector charts drawn by reportlab (no matplotlib). |
| `app/export/units.py` | Engineering-prefix formatting shared by UI and reports. |
| `app/i18n/` | Runtime translation lookup (`tr()`, `N_()`, `set_language()`). |
| `app/ui/controller.py` | `AcquisitionController` (session, data, reconnection). |
| `app/ui/main_window.py` | Window shell: navigation rail, connection bar, pages, status bar, shortcuts. |
| `app/ui/pages/*.py` | Live, Analysis, Device, Settings and About pages. |
| `app/ui/widgets/plot_widget.py` | Stacked V/I/P plots: live (follow) and overview (selection region) modes. |
| `app/ui/file_actions.py` | Import/export dialogs running in a background thread with progress. |
| `app/core/gpu_*.py` | Pre-start OpenGL probe and fallback (default / NVIDIA offload / software). |

---

## User interface

- **Live** – stacked voltage/current/power plots with selectable series,
  time-window presets, follow-live toggle (drag to look back, double-click to
  return), crosshair readout in the status bar, live tiles (value, min/max,
  moving or whole-recording average power) and energy, charge, sample rate and
  lost samples.
- **Analysis** – overview of the whole recording with a draggable selection;
  statistics per quantity, energy/charge/RMS, power-supply quality with
  recommendations, frequency spectrum (linear/log), **Markers** (segments
  between markers with duration, average/peak power, energy, charge; click a
  row to select it) and **Benchmark** (energy per inference, inferences per
  joule, throughput per watt, gross and net of the idle power). Export the
  selection or the whole recording as CSV or PDF; import CSV.
- **Device** – connection and firmware info, INA226 averaging and conversion
  times (presets and custom, with the resulting sample rate), OLED on/off,
  save as device default, clock sync with the PC and device–PC offset,
  host-side calibration (shunt, offset with "zero now", gains), device log and
  a raw command line.
- **Settings** – language, theme (dark/light/system), refresh rate, time
  window, line width, antialiasing, grid, crosshair, units (auto prefix, base,
  milli), significant digits, average-power mode, CPU indicator, OpenGL,
  baud rate, auto-reconnect, no-data timeout, host averaging, CSV format and
  PDF contents. Every change applies immediately and is saved.

Keyboard: `Ctrl+R` start/stop, `M` add a marker, `Ctrl+O` import,
`Ctrl+E` export CSV, `Ctrl+P` export PDF, `Ctrl+1…5` switch page.

### Markers

Markers are added with the `M` key or the *Marker* button while recording
(placed at the best estimate of "now": newest sample time plus the time
elapsed since it arrived), or with a right-click on any plot at the exact
point. Double-click a marker to rename it; drag it on the Analysis plot to
move it; right-click it to delete it. Markers are stored in CSV files as
trailing lines:

```
#MARKER<TAB>id<TAB>time_s<TAB>label        (add or replace)
#MARKER<TAB>id<TAB>DELETE                  (remove)
```

Later lines for the same id win, so a recording file is only ever appended
to. Tools such as pandas can skip them with `comment="#"`.

### Continuous recording

With *Save recordings automatically* (default on) every live acquisition is
written, while it runs, to `Documents/EdgePowerMeter/recording_YYYYMMDD_HHMMSS.csv`
(folder configurable). It is the same CSV format as Export CSV, flushed about
once per second, so the file is valid even after a crash. No hidden or
temporary files are created; recordings shorter than one second (accidental
Start/Stop) are deleted; existing files are never overwritten. Exporting the
whole recording as CSV offers the existing file instead of creating a
duplicate. The status bar shows the file and its size; click it to open the
folder.

---

## Translations

All UI text is written in English and wrapped in `tr()`. Catalogs for Italian,
Spanish, French and German are generated **offline on the developer machine**
by a local machine-translation model (Argos Translate models run through
CTranslate2; no cloud service), then corrected through
`app/i18n/overrides/<lang>.json`, which always wins. The tool refuses
translations that lose placeholders or brackets. See
[tools/i18n/README.md](../tools/i18n/README.md):

```bash
tools/i18n/.venv/bin/python tools/i18n/translate.py extract
tools/i18n/.venv/bin/python tools/i18n/translate.py translate --prune
tools/i18n/.venv/bin/python tools/i18n/translate.py check
```

The language defaults to the operating-system language and can be changed in
Settings; the window is rebuilt in place without losing data.

---

## Settings

`AppSettings` is persisted with `QSettings` (group `settings_v2`):

- Linux: `~/.config/EdgePowerMeter/EdgePowerMeter.conf`
- Windows: registry `HKCU\Software\EdgePowerMeter`
- macOS: `~/Library/Preferences/com.EdgePowerMeter.plist`

Values are type-checked and clamped on load, so a corrupted entry falls back
to its default. The few options that existed in 1.x are migrated.

---

## Export formats

### CSV

```
Timestamp,RelativeTime[s],Voltage[V],Current[A],Power[W]
2026-10-08 12:34:56.123,0.000000,5.012500,0.250000,1.253125
```

- `RelativeTime` is the precise (device) time axis; `Timestamp` is local
  wall-clock time with millisecond resolution, or Unix seconds if chosen.
- With *decimal comma* the separator becomes `;` for spreadsheet locales such
  as Italian or German.
- Import auto-detects separator, decimal comma, timestamp style and the
  4-column layout of older files and firmware logs.

### PDF

Key-figure tiles, recording metadata, per-quantity table (min, max, average,
std dev, RMS, peak-to-peak), energy and derived quantities (charge, power
variability, current crest factor, voltage ripple, load resistance), markers
and segment table, benchmark results, vector charts of V/I/P with min/max
envelopes and markers, power distribution histogram with percentiles,
power-supply quality with pass/fail table and recommendations, frequency
spectrum (linear and dB) with peaks, and the instrument settings
(sensor configuration and calibration) for traceability.

---

## Testing

```bash
python3 -m venv .venv && .venv/bin/pip install -e ".[dev]"
.venv/bin/python -m pytest -q
```

Tests run headless (`QT_QPA_PLATFORM=offscreen`), use temporary QSettings and
a scripted fake device (`tests/fakes.py`) that emulates firmware 1.x and 2.x,
including unplugging, silence, slow boot and dropped lines.

---

## Troubleshooting

**Permission denied on the serial port (Linux)** – add the user to the
`dialout` group and log in again: `sudo usermod -a -G dialout $USER`.

**"Firmware 1.x detected"** – the app works, but device time, lost-sample
detection, sensor configuration and clock sync need firmware 2.0
(`firmware/` folder, see HARDWARE.md).

**Lost samples increase** – the PC is not reading fast enough (very slow
machine or heavy load) or the INA226 period is below ~0.5 ms. Increase the
averaging on the Device page.

**Blank or slow plots** – disable *Hardware acceleration (OpenGL)* in
Settings, or use *Re-detect graphics on next launch* on the About page.

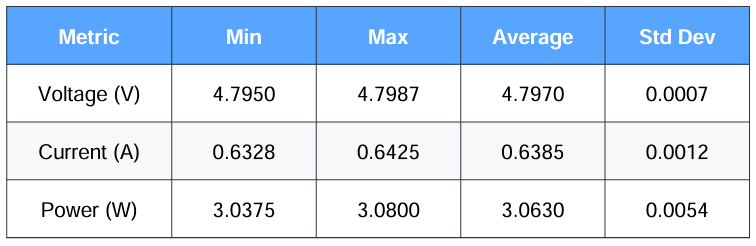
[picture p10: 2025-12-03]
assets/prototype/statistics/summary.png

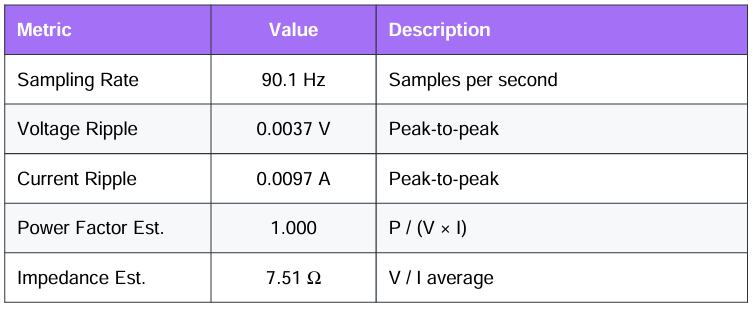
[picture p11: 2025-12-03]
assets/prototype/statistics/derived.png

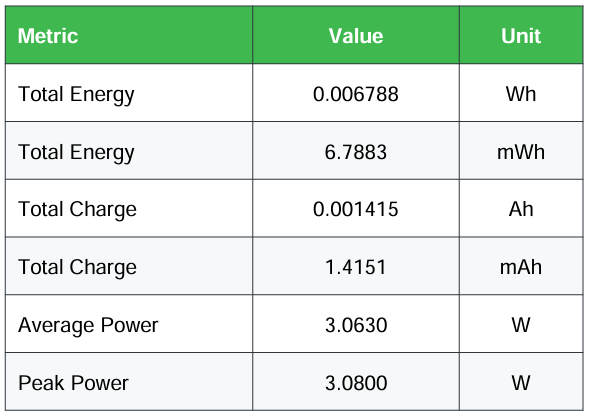
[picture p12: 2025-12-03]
assets/prototype/statistics/energy.png

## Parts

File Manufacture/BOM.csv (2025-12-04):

ID | Name | Designator | Footprint | Quantity | Manufacturer Part | Manufacturer | Supplier | Supplier Part | Price | Pins | 3DModel | Contributor | GROUP | JLCPCB Part Class | LOCTION | link
1 | BS-12-B3AA003-R | BAT1 | BAT-SMD_CR1220-2_C964724 | 1 | BS-12-B3AA003-R | MYOUNG(美阳) | LCSC | C964724 | 0.31 | 2 | BAT-SMD_CR1220-2 | lcsc |  | Extended Part |  | https://cn.bing.com/search?q=datasheet%3A+%20BS-12-B3AA003-R
2 | 100nF | C1 | C1206 | 1 | C1206F104K1RAC3083 | KEMET(基美) | LCSC | C141208 | 0.064 | 2 | C1206_L3.2-W1.6-H1.3 | LCSC |  | Extended Part |  | https://item.szlcsc.com/89171.html
3 | 12pF | C4,C5 | C1206 | 2 |  |  | Farnell |  |  | 2 | C1206_L3.2-W1.6-H1.3 | LCSC | CAPACITOR |  |  | https://item.szlcsc.com/89171.html
4 | 1977477-2 | IN2,OUT3 | CONN-TH_2P-P8.25_1977477-2 | 2 | 1977477-2 | TE Connectivity(泰科电子) | LCSC | C3656194 | 1.992 | 2 | CONN-TH_2P-P8.25_DBT30C-8.25-2P | lcsc |  | Extended Part |  | https://www.mouser.com/datasheet/2/418/7/ENG_CD_1977477_B1-2023762.pdf
5 | DSS14 | D1 | SOD-123_L2.8-W1.8-LS3.7-RD | 1 | DSS14 | 星海 | LCSC | C59293 | 0.017 | 2 | SOD-123_L2.8-W1.8-LS3.7-RD | lcsc |  | Extended Part |  | https://item.szlcsc.com/301422.html
6 | OLED DISPLAY 128x32 0.91" I2C SSD1306 STAG5 | DP1 | OLED-TH-C128-R64-D0.91-I2C-SSD1306-STAG5 | 1 |  |  |  |  |  | 4 | ImageToStl.com_led ssd1306 128x32 | priyasai1501
7 | 4.7kΩ | R1,R2 | R1206 | 2 | RMC12064.7K1%N | Tyohm(幸亚电阻) | LCSC | C269592 | 0.008 | 2 | R1206_L3.2-W1.6-H0.6 | LCSC |  | Extended Part |  | https://item.szlcsc.com/311874.html
8 | 0.01Ω | R3 | R2512 | 1 | MRF6432(2512)LR010JTS | SUP | LCSC | C76272 |  | 2 | R2512_L6.3-W3.2-H0.6 | lcsc |  | Extended Part |  | https://item.szlcsc.com/347967.html
9 | ESP32C3-SUPERMINI | U1 | COMM-SMD_16P-L22.5-W18.0-P2.54-TL | 1 | ESP32C3-SuperMini | null | LCSC | C9900147397 |  | 16 | COMM-SMD_MOUDLE-SEEEDUINO-XIAO-ESP32C3 | lcsc |  | Extended Part |  | https://www.nologo.tech/product/esp32/esp32c3SuperMini/esp32C3SuperMini.html#wifi%E5%A4%A9%E7%BA%BF
10 | INA226AIDGSR | U2 | MSOP-10_L3.0-W3.0-P0.50-LS5.0-BL | 1 | INA226AIDGSR | TI(德州仪器) | LCSC | C49851 | 0.657 | 10 | MSOP-10_L3.0-W3.0-H1.1-LS5.0-P0.50 | lcsc |  | Extended Part |  | https://item.szlcsc.com/221388.html
11 | DS1307ZN-TD | U3 | SOIC-8_L5.0-W4.0-P1.27-LS6.0-BL | 1 | DS1307ZN-TD | TDSEMIC(拓电半导体) | LCSC | C42421871 | 0.244 | 8 | SOIC-8_L4.9-W3.9-H1.7-LS6.0-P1.27 | lcsc |  | Extended Part |  | https://item.szlcsc.com/417287.html
12 | HYCW579-USBC06-680B | OUT1,IN1 | USB-C-SMD_HYCW579-USBC06-680B | 2 | HYCW579-USBC06-680B | 华宇创 | LCSC | C42400241 | 0.034 | 10 | USB-C-SMD_HYCW579-USBC06-680B | lcsc |  | Extended Part |  | https://atta.szlcsc.com/upload/public/pdf/source/20241127/7A8D0229D98E76746D52A5640C8F5C89.pdf
13 | AF Bend foot Have side Inside the bomb iron PBT White plastic 90degree | OUT2 | USB-A-TH_JTJ-USB-AF-03 | 1 | 901-131A1011D10100 | 精拓金 | LCSC | C39431 | 0.052 | 6 | USB-A-TH_4P-L14.5-W14.0-H7.6-S2.71 | 立创EDA官方封装库 |  | Extended Part |  | https://item.szlcsc.com/43640.html
14 | 32.768kHz | X1 | CRYSTAL-SMD_L3.2-W1.5 | 1 | ABS07-120-32.768KHZ-T | ABRACON | LCSC | C1985240 | 0.491 | 2 | CRYSTAL-SMD_L3.2-W1.5-1 | LCSC |  | Extended Part |  | https://atta.szlcsc.com/upload/public/pdf/source/20171201/C156245_15121213439061157573.pdf

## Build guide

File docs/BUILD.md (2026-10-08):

# Building EdgePowerMeter

This guide explains how to build EdgePowerMeter as a standalone executable for distribution.

## Table of Contents

- [Prerequisites](#prerequisites)
- [Building on Linux](#building-on-linux)
- [Building on Windows](#building-on-windows)
- [Building on macOS](#building-on-macos)
- [Build Script Reference](#build-script-reference)
- [Troubleshooting](#troubleshooting)

---

## Prerequisites

### Python Dependencies

```bash
# Required packages
pip install -e .

# Build tools
pip install pyinstaller
```

### System Dependencies

#### Linux (Debian/Ubuntu)
```bash
# For building .deb packages
sudo apt install dpkg-dev

# Optional: for smaller builds
sudo apt install upx-ucl
```

#### Windows
- No additional dependencies required

#### macOS
```bash
# Optional: for creating .app bundles
brew install create-dmg
```

---

## Building on Linux

### Quick Build

```bash
# Build everything (executable + .deb package)
python build.py all

# Or step by step:
python build.py clean   # Clean previous builds
python build.py exe     # Build executable
python build.py deb     # Create .deb package
```

### Output Files

After building, you'll find:

| File | Location | Description |
|---|---|---|
| `EdgePowerMeter` | `dist/` | Standalone executable |
| `edgepowermeter_*.deb` | `dist/` | Debian package |

### Installing the .deb Package

```bash
# Install
sudo dpkg -i dist/edgepowermeter_1.0.0_amd64.deb

# If there are dependency issues
sudo apt --fix-broken install

# Uninstall
sudo dpkg -r edgepowermeter
```

### Running the Executable

```bash
# Direct execution
./dist/EdgePowerMeter

# Or after installing .deb
edgepowermeter
```

---

## Building on Windows

### Prerequisites

1. Install [Python 3.8+](https://www.python.org/downloads/)
2. Install dependencies:
   ```cmd
   pip install -e . pyinstaller
   ```

### Building

```cmd
# Clean and build
python build.py clean
python build.py exe
```

### Output

The executable will be created at:
```
dist\EdgePowerMeter.exe
```

### Creating an Installer (Optional)

For creating a Windows installer, you can use [Inno Setup](https://jrsoftware.org/isinfo.php) or [NSIS](https://nsis.sourceforge.io/).

Example Inno Setup script (`installer.iss`):

```iss
[Setup]
AppName=EdgePowerMeter
AppVersion=1.6.0
DefaultDirName={autopf}\EdgePowerMeter
DefaultGroupName=EdgePowerMeter
OutputDir=dist
OutputBaseFilename=EdgePowerMeter_Setup

[Files]
Source: "dist\EdgePowerMeter.exe"; DestDir: "{app}"

[Icons]
Name: "{group}\EdgePowerMeter"; Filename: "{app}\EdgePowerMeter.exe"
Name: "{commondesktop}\EdgePowerMeter"; Filename: "{app}\EdgePowerMeter.exe"
```

---

## Building on macOS

### Prerequisites

```bash
pip install -e . pyinstaller
```

### Building

```bash
python build.py clean
python build.py exe
```

### Output

The app will be created at:
```
dist/EdgePowerMeter.app
```

### Creating a DMG (Optional)

```bash
# Install create-dmg
brew install create-dmg

# Create DMG
create-dmg \
    --volname "EdgePowerMeter" \
    --window-size 600 400 \
    --icon-size 100 \
    --app-drop-link 450 200 \
    dist/EdgePowerMeter.dmg \
    dist/EdgePowerMeter.app
```

---

## Build Script Reference

### Commands

| Command | Description |
|---|---|
| `python build.py clean` | Remove all build artifacts |
| `python build.py exe` | Build standalone executable |
| `python build.py deb` | Create .deb package (Linux only) |
| `python build.py all` | Clean + exe + deb |

### Configuration

Edit `build.py` to modify:

```python
APP_NAME = "EdgePowerMeter"    # Application name
VERSION = "1.6.0"               # Version number
DESCRIPTION = "..."             # Package description
AUTHOR = "Daniel Rossi"         # Author name
```

### Excluding Modules

To reduce executable size, modules can be excluded in `build.py`:

```python
"--exclude-module", "torch",
"--exclude-module", "tensorflow",
# Add more as needed
```

---

## Troubleshooting

### Large Executable Size

If the executable is too large (>100MB), you may have heavy packages like PyTorch installed. Add them to the exclude list in `build.py`:

```python
"--exclude-module", "torch",
"--exclude-module", "torchvision",
"--exclude-module", "tensorflow",
"--exclude-module", "cv2",
```

### Missing Modules at Runtime

If the app crashes with `ModuleNotFoundError`, add the module as a hidden import:

```python
"--hidden-import", "missing_module",
```

### Serial Port Access (Linux)

If the app can't access serial ports:

```bash
# Add user to dialout group
sudo usermod -a -G dialout $USER

# Log out and back in, or:
newgrp dialout
```

### Qt Platform Plugin Error (Linux)

If you see `qt.qpa.plugin: Could not load the Qt platform plugin`:

```bash
# Install Qt dependencies
sudo apt install libxcb-xinerama0 libxcb-cursor0
```

### Windows Defender False Positive

PyInstaller executables are sometimes flagged by antivirus. You can:
1. Add an exception for the executable
2. Sign the executable with a code signing certificate

### macOS Gatekeeper

If macOS blocks the app:

```bash
# Remove quarantine attribute
xattr -d com.apple.quarantine dist/EdgePowerMeter.app

# Or allow in System Preferences > Security & Privacy
```

---

## Build Artifacts

After a successful build, your `dist/` folder should contain:

```
dist/
├── EdgePowerMeter              # Linux executable
├── EdgePowerMeter.exe          # Windows executable
├── EdgePowerMeter.app/         # macOS application
└── edgepowermeter_1.0.0_amd64.deb  # Debian package
```

The `build/` folder contains intermediate files and can be safely deleted.

---

## CI/CD Integration

Example GitHub Actions workflow (`.github/workflows/build.yml`):

```yaml
name: Build

on:
  push:
    tags:
      - 'v*'

jobs:
  build-linux:
    runs-on: ubuntu-latest
    steps:
      - uses: actions/checkout@v4
      - uses: actions/setup-python@v5
        with:
          python-version: '3.10'
      - run: pip install -e . pyinstaller
      - run: python build.py all
      - uses: actions/upload-artifact@v4
        with:
          name: linux-build
          path: dist/

  build-windows:
    runs-on: windows-latest
    steps:
      - uses: actions/checkout@v4
      - uses: actions/setup-python@v5
        with:
          python-version: '3.10'
      - run: pip install -e . pyinstaller
      - run: python build.py exe
      - uses: actions/upload-artifact@v4
        with:
          name: windows-build
          path: dist/

  build-macos:
    runs-on: macos-latest
    steps:
      - uses: actions/checkout@v4
      - uses: actions/setup-python@v5
        with:
          python-version: '3.10'
      - run: pip install -e . pyinstaller
      - run: python build.py exe
      - uses: actions/upload-artifact@v4
        with:
          name: macos-build
          path: dist/
```

---

## Support

If you encounter build issues, please:

1. Check the [Troubleshooting](#troubleshooting) section
2. Search existing [GitHub Issues](https://github.com/DanielRossi1/EdgePowerMeter/issues)
3. Open a new issue with:
   - Your operating system and version
   - Python version (`python --version`)
   - Full error message/traceback
   - Steps to reproduce

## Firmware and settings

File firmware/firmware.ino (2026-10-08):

/**
 * @file firmware.ino
 * @brief EdgePowerMeter firmware: INA226 power monitor streaming over USB-CDC
 * @version 2.0.0
 *
 * Streams every INA226 conversion to the host over the serial port, using the
 * protocol described in docs/PROTOCOL.md:
 *   - CSV mode (default at boot): legacy human-readable lines
 *       Timestamp,Voltage[V],Current[A],Power[W]
 *   - RAW mode (selected by the desktop app): compact lines with a sequence
 *     number, device time in µs and raw INA226 registers, plus one wall-clock
 *     time anchor per second from the DS3231.
 *
 * Design notes:
 *   - New conversions are detected by polling the INA226 conversion-ready
 *     flag, so every sample is a fresh conversion (no duplicates) and its
 *     timestamp is taken when the flag is observed.
 *   - Polling only starts shortly before the next conversion is due; the time
 *     in between ("slack") is used for background I2C work: RTC reads and a
 *     chunked, non-blocking OLED update. Nothing long-running ever blocks the
 *     sampling path.
 *   - If the host does not drain the serial port, data lines are dropped
 *     instead of blocking; the sequence number still increments so the host
 *     can count lost samples.
 *
 * Hardware:
 *   - MCU: ESP32-C3 SuperMini (single-core RISC-V @ 160 MHz, native USB-CDC)
 *   - Power monitor: INA226 (I2C 0x40), shunt 0.01 Ω (R2512)
 *   - RTC: DS3231 (I2C 0x68), SQW -> GPIO3
 *   - Display: SSD1306 128x32 (I2C 0x3C)
 *
 * Libraries: RTClib, Adafruit SSD1306, Adafruit GFX (the INA226 library is
 * no longer needed: see INA226Lite).
 *
 * @author Daniel Rossi
 * @license Apache-2.0
 */

#include <Wire.h>
#include <RTClib.h>
#include <Preferences.h>
#include <esp_timer.h>

#include "INA226Lite.h"
#include "OLEDStatus.h"
#include "PrecisionTime.h"

// =============================================================================
// Version
// =============================================================================

#define FIRMWARE_VERSION "2.0.0"
#define FIRMWARE_NAME "EdgePowerMeter"
#define PROTOCOL_VERSION 2

// Timing diagnostics for firmware development: when 1, every 5 s the
// firmware prints "# DIAG" lines with missed conversions attributed to the
// slowest task and per-phase I2C timings. Keep 0 in releases.
#ifndef EPM_DIAG
#define EPM_DIAG 0
#endif

// Serial is the native USB-Serial/JTAG CDC (HWCDC) on the ESP32-C3 when
// "USB CDC On Boot" is enabled.
#if ARDUINO_USB_CDC_ON_BOOT && ARDUINO_USB_MODE
#define EPM_SERIAL_IS_HWCDC 1
#else
#define EPM_SERIAL_IS_HWCDC 0
#endif

// =============================================================================
// Configuration
// =============================================================================

namespace Config {
    // Pins
    constexpr uint8_t SQW_PIN = 3;  // DS3231 SQW output -> ESP32 GPIO3 (A3)

    // Display
    constexpr uint8_t SCREEN_WIDTH = 128;
    constexpr uint8_t SCREEN_HEIGHT = 32;
    constexpr int8_t OLED_RESET = -1;
    constexpr uint8_t SCREEN_ADDRESS = 0x3C;
    constexpr int64_t OLED_FRAME_INTERVAL_US = 250000;  // 4 Hz

    // INA226
    constexpr uint8_t INA226_ADDRESS = 0x40;
    constexpr uint16_t DEFAULT_AVERAGES = 4;
    constexpr uint16_t DEFAULT_BUS_CONV_US = 140;
    constexpr uint16_t DEFAULT_SHUNT_CONV_US = 140;
    constexpr float DEFAULT_SHUNT_OHM = 0.010f;
    constexpr int64_t INA_RETRY_INTERVAL_US = 5000000;
    constexpr uint8_t INA_MAX_I2C_ERRORS = 10;

    // Serial
    // The baud rate is irrelevant for native USB-CDC; kept for UART builds.
    constexpr unsigned long SERIAL_BAUD = 2000000;
    constexpr size_t SERIAL_TX_BUFFER = 4096;
    constexpr size_t SERIAL_RX_BUFFER = 256;
    constexpr uint32_t HOST_WAIT_MS = 1500;
    constexpr int64_t RELIABLE_WRITE_TIMEOUT_US = 20000;

    // RTC
    // false = production behavior: the battery-backed DS3231 keeps its time
    // across reboots and only re-syncs to compile time if it actually lost
    // power (rtc.lostPower()). Set to true only for a one-time forced sync,
    // then flash back to false. The desktop app can also set the clock with
    // the SYNC command.
    constexpr bool FORCE_RTC_UPDATE = false;

    // Scheduling of background work between conversions
    constexpr uint32_t POLL_LEAD_PERCENT = 85;  // Start polling at 85% of the period
    constexpr int64_t SLACK_GUARD_US = 60;
    // Longest single RTC step (full 7-register read, ~300 µs at 400 kHz);
    // seconds-only polls are cheaper.
    constexpr int64_t RTC_WORK_COST_US = 350;

    // OLED: if spare time never suffices (very short conversion periods, or a
    // cost estimate inflated by one slow transfer), force a little progress
    // anyway, accepting a few skipped conversions.
    constexpr int64_t OLED_FORCE_AFTER_US = 1000000;
    constexpr uint32_t OLED_MAX_FRAME_SAMPLES = 1000000;

    // INA226 configuration read-back (detects a sensor power-on reset)
    constexpr int64_t INA_CONFIG_CHECK_US = 2000000;
    constexpr int64_t INA_CONFIG_CHECK_COST_US = 300;

    // Accepted shunt values (SET SHUNT, NVS)
    constexpr float SHUNT_MIN_OHM = 1e-5f;
    constexpr float SHUNT_MAX_OHM = 100.0f;
}

// =============================================================================
// Global Objects and State
// =============================================================================

RTC_DS3231 rtc;
INA226Lite ina(Config::INA226_ADDRESS);
OLEDStatus display(Config::SCREEN_WIDTH, Config::SCREEN_HEIGHT, Config::OLED_RESET);
PrecisionTime precisionTime(rtc, Config::SQW_PIN);

enum class OutputMode : uint8_t { Csv, Raw };

struct DeviceSettings {
    uint16_t averages;
    uint16_t busConvUs;
    uint16_t shuntConvUs;
    float shuntOhm;
    bool oledEnabled;
};

DeviceSettings settings = {
    Config::DEFAULT_AVERAGES,
    Config::DEFAULT_BUS_CONV_US,
    Config::DEFAULT_SHUNT_CONV_US,
    Config::DEFAULT_SHUNT_OHM,
    true,
};

OutputMode outputMode = OutputMode::Csv;
bool streamEnabled = true;
bool inaOk = false;
bool rtcOk = false;

// =============================================================================
// Output Helpers
// =============================================================================

namespace Out {
    char* putU32(char* p, uint32_t v) {
        char tmp[10];
        uint8_t n = 0;
        do {
            tmp[n++] = static_cast<char>('0' + v % 10);
            v /= 10;
        } while (v);
        while (n) *p++ = tmp[--n];
        return p;
    }

    char* putU64(char* p, uint64_t v) {
        char tmp[20];
        uint8_t n = 0;
        do {
            tmp[n++] = static_cast<char>('0' + v % 10);
            v /= 10;
        } while (v);
        while (n) *p++ = tmp[--n];
        return p;
    }

    char* putI64(char* p, int64_t v) {
        if (v < 0) {
            *p++ = '-';
            return putU64(p, static_cast<uint64_t>(-(v + 1)) + 1);
        }
        return putU64(p, static_cast<uint64_t>(v));
    }

    /** @brief Print value / 10^decimals with exactly `decimals` digits. */
    char* putScaled(char* p, int64_t value, uint8_t decimals) {
        if (value < 0) {
            *p++ = '-';
            value = -value;
        }
        uint64_t scale = 1;
        for (uint8_t i = 0; i < decimals; i++) scale *= 10;
        p = putU64(p, static_cast<uint64_t>(value) / scale);
        if (decimals) {
            *p++ = '.';
            uint64_t frac = static_cast<uint64_t>(value) % scale;
            for (int8_t i = decimals - 1; i >= 0; i--) {
                p[i] = static_cast<char>('0' + frac % 10);
                frac /= 10;
            }
            p += decimals;
        }
        return p;
    }

    char* putFixed(char* p, double value, uint8_t decimals) {
        double scale = 1.0;
        for (uint8_t i = 0; i < decimals; i++) scale *= 10.0;
        const double scaled = value * scale;
        const int64_t rounded = static_cast<int64_t>(scaled < 0 ? scaled - 0.5 : scaled + 0.5);
        return putScaled(p, rounded, decimals);
    }

    /** @brief Write a data line, or drop it if the TX buffer cannot take it. */
    bool writeData(const char* buf, size_t len) {
        if (Serial.availableForWrite() < static_cast<int>(len)) {
            return false;
        }
        Serial.write(reinterpret_cast<const uint8_t*>(buf), len);
        return true;
    }

    /** @brief Write a line that must not be lost (replies), waiting briefly for room. */
    void writeReliable(const char* buf, size_t len) {
        const int64_t deadline = esp_timer_get_time() + Config::RELIABLE_WRITE_TIMEOUT_US;
        while (Serial.availableForWrite() < static_cast<int>(len) && esp_timer_get_time() < deadline) {
            delayMicroseconds(200);
        }
        Serial.write(reinterpret_cast<const uint8_t*>(buf), len);
    }

    void line(const char* text) {
        char buf[128];
        const size_t n = strnlen(text, sizeof(buf) - 2);
        memcpy(buf, text, n);
        buf[n] = '\n';
        writeReliable(buf, n + 1);
    }

    /** @brief Informational line ("# ..."), ignored by host parsers. */
    void info(const char* text) {
        char buf[128];
        snprintf(buf, sizeof(buf), "# %s", text);
        line(buf);
    }
}

// =============================================================================
// Persistent Settings (NVS)
// =============================================================================

namespace Storage {
    constexpr const char* NAMESPACE = "epm";

    void load() {
        Preferences prefs;
        if (!prefs.begin(NAMESPACE, true)) {
            return;  // Nothing saved yet
        }
        const uint16_t avg = prefs.getUShort("avg", Config::DEFAULT_AVERAGES);
        const uint16_t vct = prefs.getUShort("vct", Config::DEFAULT_BUS_CONV_US);
        const uint16_t ict = prefs.getUShort("ict", Config::DEFAULT_SHUNT_CONV_US);
        const float shunt = prefs.getFloat("shunt", Config::DEFAULT_SHUNT_OHM);
        const bool oled = prefs.getBool("oled", true);
        prefs.end();

        if (INA226Lite::isValidAverage(avg)) settings.averages = avg;
        if (INA226Lite::isValidConversionTime(vct)) settings.busConvUs = vct;
        if (INA226Lite::isValidConversionTime(ict)) settings.shuntConvUs = ict;
        if (shunt >= Config::SHUNT_MIN_OHM && shunt <= Config::SHUNT_MAX_OHM) settings.shuntOhm = shunt;
        settings.oledEnabled = oled;
    }

    bool save() {
        Preferences prefs;
        if (!prefs.begin(NAMESPACE, false)) {
            return false;
        }
        bool ok = prefs.putUShort("avg", settings.averages) > 0;
        ok = prefs.putUShort("vct", settings.busConvUs) > 0 && ok;
        ok = prefs.putUShort("ict", settings.shuntConvUs) > 0 && ok;
        ok = prefs.putFloat("shunt", settings.shuntOhm) > 0 && ok;
        ok = prefs.putBool("oled", settings.oledEnabled) > 0 && ok;
        prefs.end();
        return ok;
    }
}

// =============================================================================
// Sampling
// =============================================================================

namespace Sampling {
    uint32_t seq = 0;
    uint32_t periodUs = 1120;
    int64_t lastReadyUs = 0;
    int64_t nextPollUs = 0;
    int64_t lastRetryUs = 0;
    int64_t lastConfigCheckUs = 0;
    uint8_t i2cErrors = 0;

    // Accumulators for the OLED frame (averages since the previous frame)
    uint64_t frameBusSum = 0;
    int64_t frameShuntSum = 0;
    double framePowerSum = 0.0;
    uint32_t frameSamples = 0;

    void restartTiming(int64_t now) {
        periodUs = ina.periodUs();
        lastReadyUs = now;
        nextPollUs = now + static_cast<int64_t>(periodUs) * Config::POLL_LEAD_PERCENT / 100;
    }

    /** @brief (Re)initialize the INA226 with the current settings. */
    bool initSensor() {
        inaOk = ina.begin()
            && ina.configure(settings.averages, settings.busConvUs, settings.shuntConvUs);
        i2cErrors = 0;
        restartTiming(esp_timer_get_time());
        return inaOk;
    }

    bool applyConfig() {
        if (!inaOk) {
            return true;  // Applied on the next successful (re)initialization
        }
        if (!ina.configure(settings.averages, settings.busConvUs, settings.shuntConvUs)) {
            return false;
        }
        restartTiming(esp_timer_get_time());
        return true;
    }

    /** @brief Time available for background work before the next poll. */
    int64_t slackUs(int64_t now) {
        if (!inaOk) {
            return INT32_MAX;
        }
        return nextPollUs - now - Config::SLACK_GUARD_US;
    }

    void onI2cError() {
        if (++i2cErrors >= Config::INA_MAX_I2C_ERRORS) {
            inaOk = false;
            lastRetryUs = esp_timer_get_time();
            Out::info("ERROR INA226 not responding");
        }
    }

    void emitSample(uint32_t s, int64_t t, uint16_t bus, int16_t shunt) {
        char buf[96];
        char* p = buf;

        if (outputMode == OutputMode::Raw) {
            *p++ = 'D';
            *p++ = ',';
            p = Out::putU32(p, s);
            *p++ = ',';
            p = Out::putI64(p, t);
            *p++ = ',';
            p = Out::putU32(p, bus);
            *p++ = ',';
            p = Out::putI64(p, shunt);
        } else {
            precisionTime.formatTimestamp(t, p, 24);
            p += strlen(p);
            *p++ = ',';
            // Bus LSB is exactly 1.25 mV = 125e-5 V
            p = Out::putScaled(p, static_cast<int64_t>(bus) * 125, 5);
            const double volts = bus * static_cast<double>(INA226Lite::BUS_LSB_V);
            const double amps = shunt * static_cast<double>(INA226Lite::SHUNT_LSB_V) / settings.shuntOhm;
            *p++ = ',';
            p = Out::putFixed(p, amps, 6);
            *p++ = ',';
            p = Out::putFixed(p, volts * amps, 6);
        }
        *p++ = '\n';
        Out::writeData(buf, static_cast<size_t>(p - buf));
    }

    void handleSample(int64_t t, uint16_t bus, int16_t shunt) {
        const uint32_t s = seq++;

        frameBusSum += bus;
        frameShuntSum += shunt;
        framePowerSum += (bus * static_cast<double>(INA226Lite::BUS_LSB_V))
            * (shunt * static_cast<double>(INA226Lite::SHUNT_LSB_V) / settings.shuntOhm);
        frameSamples++;

        if (streamEnabled) {
            emitSample(s, t, bus, shunt);
        }
    }

    /** @brief Poll the INA226 once; read and emit a sample if one is ready. */
#if EPM_DIAG
    uint32_t dPollMax = 0, dReadMax = 0, dEmitMax = 0, dPollSum = 0, dReadSum = 0, dEmitSum = 0, dN = 0, dPolls = 0;
#endif
    void step(int64_t now) {
        bool ready = false;
#if EPM_DIAG
        const int64_t p0 = esp_timer_get_time();
#endif
        const bool pollOk = ina.pollConversionReady(ready);
#if EPM_DIAG
        const uint32_t dp = static_cast<uint32_t>(esp_timer_get_time() - p0);
        dPolls++; dPollSum += dp; if (dp > dPollMax) dPollMax = dp;
#endif
        if (!pollOk) {
            onI2cError();
            return;
        }
        if (!ready) {
            // Conversions stopped (e.g. sensor power glitch reset its config)
            const int64_t stallLimit = 2 * static_cast<int64_t>(periodUs) + 100000;
            if (now - lastReadyUs > stallLimit) {
                Out::info("WARN INA226 stalled, reinitializing");
                initSensor();
            }
            return;
        }

        const int64_t t = esp_timer_get_time();
        uint16_t bus;
        int16_t shunt;
        if (!ina.readRaw(bus, shunt)) {
            onI2cError();
            return;
        }
#if EPM_DIAG
        const int64_t r1 = esp_timer_get_time();
#endif
        i2cErrors = 0;
        lastReadyUs = t;
        nextPollUs = t + static_cast<int64_t>(periodUs) * Config::POLL_LEAD_PERCENT / 100;
        handleSample(t, bus, shunt);
#if EPM_DIAG
        const uint32_t dr = static_cast<uint32_t>(r1 - t), de = static_cast<uint32_t>(esp_timer_get_time() - r1);
        dN++; dReadSum += dr; dEmitSum += de; if (dr > dReadMax) dReadMax = dr; if (de > dEmitMax) dEmitMax = de;
#endif
    }

    /**
     * @brief Read back the INA226 configuration register. A sensor power
     * glitch resets it to its defaults while conversions keep running, which
     * the stall check cannot notice; restore our configuration if so.
     */
    void checkConfig(int64_t now) {
        lastConfigCheckUs = now;
        uint16_t config = 0;
        if (!ina.readConfig(config)) {
            onI2cError();
            return;
        }
        if (config != ina.configValue()) {
            Out::info("WARN INA226 configuration lost (power glitch?), reconfiguring");
            if (!applyConfig()) {
                onI2cError();
            }
        }
    }

    bool configCheckDue(int64_t now) {
        if (!inaOk) return false;
        const int64_t since = now - lastConfigCheckUs;
        if (since < Config::INA_CONFIG_CHECK_US) return false;
        // Use spare time; without any, check anyway every few intervals
        return slackUs(now) >= Config::INA_CONFIG_CHECK_COST_US
            || since >= 5 * Config::INA_CONFIG_CHECK_US;
    }

    void retryIfDue(int64_t now) {
        if (now - lastRetryUs < Config::INA_RETRY_INTERVAL_US) return;
        lastRetryUs = now;
        if (initSensor()) {
            Out::info("INA226 initialized");
        } else {
            Out::info("ERROR INA226 not found");
        }
    }
}

// =============================================================================
// Time Anchors
// =============================================================================

namespace Anchors {
    void emit() {
        if (!precisionTime.hasAnchor()) return;
        char buf[64];
        char* p = buf;
        *p++ = 'T';
        *p++ = ',';
        p = Out::putI64(p, precisionTime.anchorUs());
        *p++ = ',';
        p = Out::putU32(p, precisionTime.anchorEpoch());
        *p++ = ',';
        *p++ = precisionTime.anchorSource() == PrecisionTime::Source::Sqw ? 'S' : 'P';
        *p++ = '\n';
        Out::writeData(buf, static_cast<size_t>(p - buf));
    }
}

// =============================================================================
// Display
// =============================================================================
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
void loop() {
    for (;;) {
        serviceOnce();
    }
}

static void serviceOnce() {
    int64_t now = esp_timer_get_time();

    // 1. Sampling has priority
    if (inaOk) {
        if (now >= Sampling::nextPollUs) {
            DIAG_T0();
            Sampling::step(now);
            DIAG_TASK(0);
#if EPM_DIAG
            Diag::afterPoll();
#endif
        }
    } else {
        Sampling::retryIfDue(now);
    }

    // 2. Host commands (CPU only, cheap)
    {
        DIAG_T0();
        Commands::poll();
        DIAG_TASK(1);
    }

    // 3. Background I2C work, only in the slack before the next conversion
    now = esp_timer_get_time();
    precisionTime.update(now);
    if (precisionTime.workPending(now)
        && (Sampling::slackUs(now) >= Config::RTC_WORK_COST_US || precisionTime.overdue(now))) {
        DIAG_T0();
        if (precisionTime.service(now) && outputMode == OutputMode::Raw && streamEnabled) {
            Anchors::emit();
        }
        DIAG_TASK(2);
    }

    now = esp_timer_get_time();
    if (Sampling::configCheckDue(now)) {
        DIAG_T0();
        Sampling::checkConfig(now);
        DIAG_TASK(3);
    }

    {
        DIAG_T0();
        Display::service(esp_timer_get_time());
        DIAG_TASK(4);
    }
#if EPM_DIAG
    Diag::print(esp_timer_get_time());
#endif
}

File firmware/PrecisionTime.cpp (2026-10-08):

/**
 * @file PrecisionTime.cpp
 * @brief Implementation of DS3231 time anchors with µs device time
 * @version 2.0.0
 *
 * @author Daniel Rossi
 * @license Apache-2.0
 */

#include "PrecisionTime.h"

#include <Wire.h>
#include <esp_timer.h>

PrecisionTime* PrecisionTime::_instance = nullptr;

namespace {
    bool isBcd(uint8_t v) {
        return (v & 0x0F) <= 9 && (v >> 4) <= 9;
    }

    uint8_t bcdToBin(uint8_t v) {
        return static_cast<uint8_t>((v >> 4) * 10 + (v & 0x0F));
    }

    uint8_t binToBcd(uint8_t v) {
        return static_cast<uint8_t>(((v / 10) << 4) | (v % 10));
    }

    /** Floor division of a signed µs interval into whole seconds. */
    int64_t floorSeconds(int64_t us) {
        int64_t s = us / 1000000;
        if (us % 1000000 < 0) s -= 1;
        return s;
    }
}

PrecisionTime::PrecisionTime(RTC_DS3231& rtc, uint8_t sqwPin)
    : _rtc(rtc)
    , _sqwPin(sqwPin)
    , _rtcOk(false)
    , _edgeUs(0)
    , _edgeCount(0)
    , _mux(portMUX_INITIALIZER_UNLOCKED)
    , _processedEdges(0)
    , _lastEdgeUs(0)
    , _haveEdgeRef(false)
    , _sqwActive(false)
    , _startUs(0)
    , _havePolledSecond(false)
    , _lastPolledSecond(0)
    , _lastPollUs(0)
    , _lastAttemptUs(0)
    , _lastChangeUs(0)
    , _nextPollUs(0)
    , _windowStartUs(0)
    , _windowTight(false)
    , _windowEndUs(0)
    , _boundaryPending(false)
    , _pendingBoundaryUs(0)
    , _anchorUs(0)
    , _anchorEpoch(NO_RTC_EPOCH)
    , _anchorSrc(Source::None)
    , _haveCoarseAnchor(false)
    , _implausibleReads(0)
    , _cachedEpoch(0)
    , _cachedDate{0}
{
    _instance = this;
}

// The DS3231 increments its seconds register on the falling edge of the
// 1 Hz SQW output (datasheet: after a seconds write the output goes high
// 500 ms later and falls at the next second), so a falling edge marks the
// start of a new RTC second.
//
// Note: the Arduino GPIO interrupt dispatcher is not placed in IRAM on this
// core, so an edge that occurs during a flash operation (SAVE) is
// timestamped late. service() rejects such edges by checking their spacing.
void IRAM_ATTR PrecisionTime::onSqwFallingEdge() {
    PrecisionTime* self = _instance;
    if (!self) return;
    const int64_t now = esp_timer_get_time();
    portENTER_CRITICAL_ISR(&self->_mux);
    if (self->_edgeCount == 0 || now - self->_edgeUs >= SQW_DEBOUNCE_US) {
        self->_edgeUs = now;
        self->_edgeCount = self->_edgeCount + 1;
    }
    portEXIT_CRITICAL_ISR(&self->_mux);
}

void PrecisionTime::begin(bool rtcAvailable) {
    _rtcOk = rtcAvailable;
    _startUs = esp_timer_get_time();
    _anchorUs = 0;
    _anchorEpoch = NO_RTC_EPOCH;
    _anchorSrc = Source::None;
    _haveCoarseAnchor = false;
    if (!_rtcOk) {
        return;
    }

    // Coarse anchor so CSV timestamps are valid immediately; refined by the
    // first SQW edge or polled boundary.
    for (uint8_t attempt = 0; attempt < 3 && !_haveCoarseAnchor; attempt++) {
        uint32_t epoch;
        if (readTime(epoch)) {
            _anchorEpoch = epoch;
            _anchorUs = esp_timer_get_time();
            _haveCoarseAnchor = true;
        }
    }

    _rtc.writeSqwPinMode(DS3231_SquareWave1Hz);
    pinMode(_sqwPin, INPUT_PULLUP);  // SQW is open drain
    attachInterrupt(digitalPinToInterrupt(_sqwPin), onSqwFallingEdge, FALLING);
    startSearch(esp_timer_get_time());
}

void PrecisionTime::readEdge(int64_t& edgeUs, uint32_t& edgeCount) const {
    portENTER_CRITICAL(&_mux);
    edgeUs = _edgeUs;
    edgeCount = _edgeCount;
    portEXIT_CRITICAL(&_mux);
}

void PrecisionTime::startSearch(int64_t nowUs) {
    _boundaryPending = false;
    _havePolledSecond = false;
    _nextPollUs = 0;
    _lastPollUs = nowUs;
    _lastAttemptUs = nowUs;
    _lastChangeUs = nowUs;
    _windowStartUs = 0;
    _windowTight = false;
    _windowEndUs = 0;
}

void PrecisionTime::openWindow(int64_t boundaryUs, bool tight) {
    _windowStartUs = boundaryUs + 1000000 - POLL_WINDOW_LEAD_US;
    _windowEndUs = boundaryUs + 1000000 + POLL_DEADLINE_US;
    _windowTight = tight;
    _nextPollUs = _windowStartUs;
}

void PrecisionTime::update(int64_t nowUs) {
    if (!_rtcOk) return;

    if (_sqwActive && nowUs - _lastEdgeUs > SQW_TIMEOUT_US) {
        // Edges stopped (SQW not wired or RTC fault): fall back to polling
        _sqwActive = false;
        startSearch(nowUs);
        return;
    }
    if (!_sqwActive && _windowTight && nowUs > _windowEndUs) {
        // The expected boundary was not seen in time: keep searching with
        // the slower forced polling instead of hammering the bus.
        _windowTight = false;
    }
}

bool PrecisionTime::workPending(int64_t nowUs) const {
    if (!_rtcOk) return false;

    int64_t edgeUs;
    uint32_t edgeCount;
    readEdge(edgeUs, edgeCount);
    if (edgeCount != _processedEdges) return true;

    if (_sqwActive) return false;

    // Give the SQW interrupt a chance before starting to poll
    if (_processedEdges == 0 && nowUs - _startUs < SQW_TIMEOUT_US) return false;

    return _boundaryPending || nowUs >= _nextPollUs;
}

bool PrecisionTime::overdue(int64_t nowUs) const {
    if (!workPending(nowUs)) return false;

    int64_t edgeUs;
    uint32_t edgeCount;
    readEdge(edgeUs, edgeCount);
    if (edgeCount != _processedEdges) {
        return nowUs - edgeUs > EDGE_DEADLINE_US;
    }

    if (_boundaryPending) {
        return nowUs - _pendingBoundaryUs > PENDING_READ_DEADLINE_US;
    }

    // Polling: make sure polls happen even without slack, often enough to
    // bracket the boundary tightly (inside a tight window) or to find it at
    // all (while searching). A stuck RTC (seconds never change) is polled
    // only rarely so it cannot starve sampling.
    const int64_t sinceAttempt = nowUs - _lastAttemptUs;
    if (_windowTight && _windowStartUs != 0) {
        return sinceAttempt >= POLL_FORCED_INTERVAL_US;
    }
    const bool stuck = nowUs - _lastChangeUs > 3000000;
    return sinceAttempt >= (stuck ? 200000 : POLL_SEARCH_FORCED_US);
}

bool PrecisionTime::readSeconds(uint8_t& seconds) {
    // Single transaction (repeated start): the bus is shared with sampling.
    Wire.beginTransmission(RTC_ADDRESS);
    Wire.write(static_cast<uint8_t>(0x00));
    Wire.endTransmission(false);
    if (Wire.requestFrom(RTC_ADDRESS, static_cast<uint8_t>(1)) != 1) return false;
    const uint8_t bcd = Wire.read() & 0x7F;
    if (!isBcd(bcd)) return false;
    seconds = bcdToBin(bcd);
    return seconds < 60;
}
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

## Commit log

2025-11-29 EdgePowerMeter Version 0 first upload
    [BOM.csv, EdgePowerMeter.fzz, EdgePowerMeter_bom.csv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]
2025-12-01 added SQW and improved data read
    [EdgePowerMeter.fzz]
2025-12-03 v1.3.0: Relative time axis, improved PDF graphs, multi-platform CI/CD
    - Time axis now starts from 0 (relative time instead of absolute)
    - Improved PDF report graphs (better colors, visibility, formatting)
    - Reorganized Start/Stop buttons in connection bar
    - Fixed acquisition race condition bug
    - Added GitHub Actions workflow for automated multi-platform builds
    - Added ARM64 support (Linux ARM, macOS Apple Silicon)
    - Firmware: increased output rate to 100Hz (was 10Hz)
    [firmware.ino]
2025-12-03 fix: free disk space before creating macOS ARM DMG
2025-12-03 fix: aggressive disk cleanup for macOS ARM build
2025-12-03 fix: use zip instead of dmg for macOS ARM to save disk space
2025-12-04 updated PCB design and exported projects
    [BOM.csv, EdgePowerMeter_Altium.schdoc, PickAndPlace.csv]
2025-12-06 feat: Add DC system analysis, power supply quality metrics, and sampling rate control
    - Refactored harmonic_analysis.py for DC systems (removed AC constraints)
    - Added power_supply_quality.py module with ripple, load regulation, and stability analysis
    - Fixed duration calculation bug (unix_time → relative_time)
    - Fixed negative energy values by clamping sensor readings
    - Added sampling rate control with subsampling capability
    - Added SampleRateController for time-based subsampling
    - Added sample rate display in UI
    - Updated PDF report with power supply quality section
    [EdgePowerMeter_bom.csv]
2025-12-08 Release 1.6.0: sampling fixes and CPU monitor
    [firmware.ino, serial_reader.py]
2026-07-22 Release 1.7.0: firmware fixes, serial watchdog, PDF report fixes, plot UX, AppImage packaging
    [firmware.ino, serial_reader.py]
2026-07-22 Fix v1.7.0 regressions: false stale-connection warning, blind OpenGL trust
    - Fix SerialReader watchdog firing a false \"stale\" warning on every
    normal connection to hardware where the RTC's SQW pin isn't wired:
    firmware boot alone (display splash + RTC + ~2.5s SQW timeout +
    INA226 init) can take ~3.6s, longer than the 3s STALE_WARNING_S
    threshold. Pre-first-sample silence now uses its own, more generous
    grace period (8s warn / 20s fatal) separate from the tighter
    mid-stream stall detection (3s / 15s).
    - Fix PlotWidget trusting \`import OpenGL\` as proof GL rendering works.
    Sandboxed installs (snap) can bundle PyOpenGL while the system GL
    driver - hardware and the swrast soft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
    [serial_reader.py, test_plot_widget_opengl.py]
2026-07-22 Add resilient serial port enumeration and GPU rendering preflight
    - Fix PortDiscovery losing the entire port list when pyserial's Linux
    backend raises TypeError constructing one device's info (int(None)
    on a sysfs attribute unreadable under snap strict confinement
    without raw-usb/hardware-observe granted). Falls back to scanning
    devices individually so one bad port can't hide the rest, and adds
    a reusable None-safe accessor for vid/pid/serial_number/description/
    hwid instead of assuming they're always populated.
    - Add a GPU rendering preflight (app.core.gpu_preflight) that runs
    before QApplication exists: probes GL in an isolated subprocess
    (gpu_probe.py), and on failure trie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
    [test_gpu_detect.py]
2026-10-08 Release 2.0.0: new UI, protocol v2, i18n, recorder, analysis tools, packaging fixes
    [INA226Lite.cpp, OLEDStatus.cpp, PrecisionTime.cpp]
2026-10-08 Fix snap startup on hybrid GPUs, PySide6 6.12 crash, stale samples after reconnect, snap recordings folder; Node 24 CI actions; new screenshots
    [fakes.py, protocol.py, serial_reader.py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]
